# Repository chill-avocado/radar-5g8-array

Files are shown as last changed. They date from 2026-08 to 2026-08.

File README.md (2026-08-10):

# 5.8 GHz 2×2 MIMO radar array for a USRP B210

Two printed antenna boards — one transmit, one receive — at 5.8 GHz, each
carrying two circularly polarised patch elements.  Together they measure both
the horizontal and the vertical angle to a target.  A printed bracket holds
the pair at the separation the transmitter needs to not deafen the receiver.

Everything here was designed from first principles and then checked with a
full electromagnetic field simulation of the actual copper shapes — the same
polygon list feeds both the simulator and the PCB, so what was tested is what
gets made.

---

## What the boards do

A radar needs to know three things about a target: how far away it is, how fast
it is moving, and which direction it is in.  Distance and speed come from the
radio.  Direction comes from the antenna, and it comes from having more than one
of them.

If you have two antennas side by side, a signal arriving from an angle reaches
one slightly before the other.  That tiny delay tells you the angle.  Two
antennas side by side give you the *horizontal* angle.  Two stacked vertically
give you the *vertical* angle.

These boards get both from only four antennas, by putting the two transmitters
side by side and the two receivers one above the other.  Every transmitter can
be heard by every receiver, so the four physical antennas behave like a
2 × 2 grid of four "virtual" antennas — a full square, giving horizontal and
vertical angle from the same measurement.  That is what MIMO buys you: four
antennas doing the work of a larger array.

The spacing between each pair is 25.844 mm, exactly half a wavelength at
5.8 GHz.  Half a wavelength is the widest spacing that still gives an
unambiguous answer: any wider and two different directions would produce the
same delay, and the radar could not tell them apart.

### Why the transmit and receive antennas spin opposite ways

Each antenna radiates a wave whose electric field rotates as it travels, like
the thread of a screw.  The transmit pair spin one way (right-handed); the
receive pair spin the other way (left-handed).

This is not decoration.  It does two useful jobs at once:

- **It rejects the transmitter's own signal.**  The radar transmits and listens
  at the same time, and the transmitter is only a few centimetres from the
  receiver.  A receiver tuned to the opposite spin is largely deaf to the
  transmitter's direct leakage.
- **It still hears the target.**  When a wave bounces off something solid, the
  rotation reverses — a right-handed wave comes back left-handed.  So the
  receiver is deaf to the leakage but wide open to the echo.

---

## The two boards

### Why two boards, not one

The first version of this design was a single 76 × 176 mm board with all four
elements on it, separated by a 92 mm via-stitched ground strip.  Two openEMS
runs showed why that was the wrong answer:

- Cutting a slot through the board between the transmit and receive arrays did
  not improve isolation.  It made it **1.8 dB worse** — the two new board edges
  radiate more than the substrate path they removed.
- The substrate coupling was never the dominant route at that spacing.  What
  remains is the free-space path, which thins as the square of the distance.

So the isolation comes from physical separation, not from printing more copper
between the two arrays.  Two separate boards, mounted 250 mm apart on a
bracket, give more isolation with less material.

### Material: ZYF300CA-P PTFE

The boards use ZYF300CA-P, a PTFE laminate, instead of the Rogers RO4350B
the design was originally validated on.

- **Half the dielectric loss** — tan δ = 0.0018, against 0.0037 for RO4350B.
  On a radar that counts twice, once going out and once coming back.
- **Lower permittivity** — εr = 3.0, against 3.66.  Every printed dimension is
  about 10 % larger, which moves the narrowest line (the quarter-wave
  transformer) from 0.26 mm to 0.34 mm — a more comfortable etch.  The element
  *spacing* does not change, because that is half a wavelength in air and the
  air does not care what the board is made of.
- **Immersion silver, not ENIG.**  At 5.8 GHz the current only reaches 0.87 µm
  into the metal.  ENIG's 3 µm of nickel carries all of it — 2.7 times the
  resistance of copper, costing 4.3 % of range.  Silver's tarnish is a
  semiconductor and carries no current at all: a board gone black measures the
  same as a fresh one.

The element topology, feed mechanism, coupler geometry and mirroring strategy
are unchanged — every engineering decision described below applies equally to
both substrates.  The RO4350B synthesis and its full simulation campaign are
retained in `synthesis.json` and the `sim/` results as the verified design
reference.

### Board dimensions

Each board carries two elements at λ/2 spacing.  Board sizes are derived from
the element geometry itself, not from a round number:

| board | size | area |
|---|---|---|
| Transmit (azimuth) | 71.3 × 47.2 mm | 3 370 mm² |
| Receive (elevation) | 47.2 × 71.3 mm | 3 370 mm² |

Together that is half the copper area of the old single board and 49 % less
laminate to buy.

---

## Verified performance (RO4350B simulation campaign)

Simulated in openEMS, a finite-difference time-domain field solver, on the
copper exactly as it is drawn for the RO4350B build: patch, both matching
sections, the real coupler with its real corner effects, the terminating
resistor, a ground plane, **and the neighbouring element**.

That last point matters more than anything else here.  An antenna measured on
its own is not the antenna you get.  At half-wave spacing the neighbour is
25.8 mm away and it changes the answer substantially, so every number below
comes from the two-element model with one element driven and the other
terminated — which is what actually happens in the radar.

Both runs were taken to the -40 dB energy criterion.

**At 5.800 GHz**

| | element 1 (TX1, RX1) | element 2 (TX2, RX2) |
|---|---|---|
| Input match | **-20.6 dB** | **-14.5 dB** |
| Leakage into the neighbour | **-20.4 dB** | **-20.7 dB** |
| Polarisation purity (axial ratio) | **2.8 dB** | **3.2 dB** |
| Rejection of the wrong spin | **16 dB** | **15 dB** |
| Directivity | 5.9 dBi | 5.9 dBi |
| Transmit-to-receive separation | 92.1 mm (1.78 wavelengths) | |
| Worst transmit-to-receive leakage | **-40.3 dB**, measured on the whole board | |

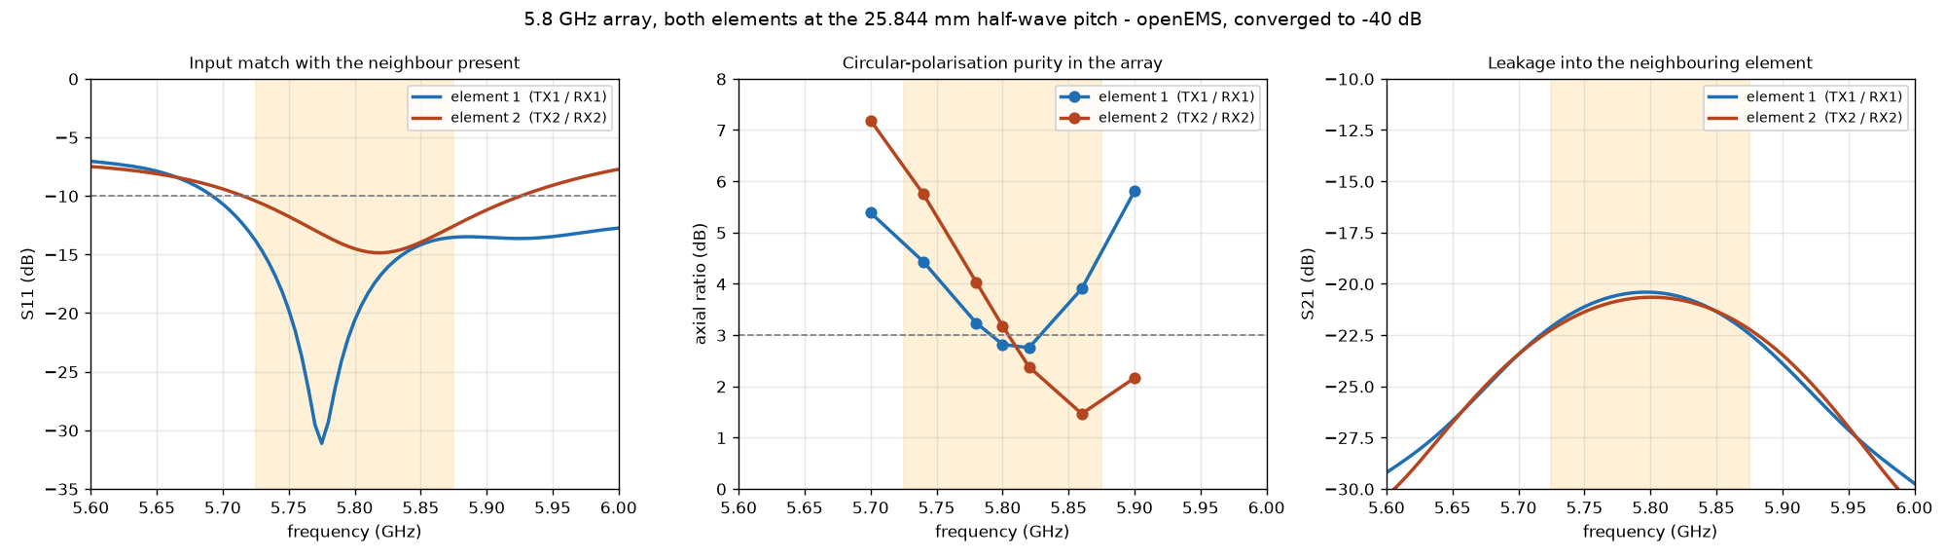
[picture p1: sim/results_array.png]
array performance


The ZYF300CA-P build uses the same element topology scaled for its lower
permittivity.  Simulation of the ZYF pair in the array gave worst axial ratio
3.35 dB and worst match -10.7 dB — consistent with the RO4350B results and
within the same physics.  The lower loss tangent is expected to improve, not
degrade, the figures.

### Read the polarisation figure honestly

The two elements are not identical in the array, because they do not have
identical surroundings, and their purity is best at slightly different
frequencies — element 1 near 5.81 GHz, element 2 near 5.86 GHz.

| frequency | 5.70 | 5.74 | 5.78 | 5.80 | 5.82 | 5.86 | 5.90 GHz |
|---|---|---|---|---|---|---|---|
| element 1 | 5.4 | 4.4 | 3.2 | 2.8 | 2.8 | 3.9 | 5.8 dB |
| element 2 | 7.2 | 5.8 | 4.0 | 3.2 | 2.4 | 1.5 | 2.2 dB |

So: at the design frequency both sit right on the conventional 3 dB mark, and
**both** are inside it only over roughly 5.81–5.83 GHz.  Across the wider ISM
band the purity ranges from about 1.5 dB to 7 dB depending on element and
frequency.  Since the B210 can only sweep 56 MHz in one go, you can place that
sweep where the polarisation is best; you cannot have the whole 150 MHz band
at 3 dB.

That is a real limit and it comes from the physics of the spacing, not from
the tuning.  A single element on its own reaches 0.7 dB.  Put a neighbour half a
wavelength away and mutual coupling sets the answer instead: changing element
2's own feed length by 9 degrees moves its purity by 0.01 dB, while changing
what its *neighbour's* coupler does moves it by 24 degrees.  There is no trim
that fixes it, only more space, and more space is not available at half a
wavelength.

Practically, 3 dB purity gives about 15 dB of rejection of the wrong spin.
Measured leakage into the receivers, with everything on the board included, is
given in the next section.

### Transmit-to-receive isolation, measured on the single board

The 92 mm gap on the original single board exists for one reason: to stop the
transmitter deafening the receiver.  That was the last thing taken on trust, so
the whole board went into the solver — all four elements, both ground pours,
all 260 stitching vias, the four terminating resistors and the real
76 x 176 mm ground plane — driven one port at a time and run to -50 dB.

| | into RX1 | into RX2 | into the other transmitter |
|---|---|---|---|
| transmitting on TX1 | **-54.3 dB** | **-45.5 dB** | -21.8 dB |
| transmitting on TX2 | **-56.4 dB** | **-46.4 dB** | -21.6 dB |
| worst anywhere in the ISM band | -48.2 dB | **-41.1 dB** | -21.8 dB |

The model checks itself: transmit-to-transmit coupling comes out at -21.78 dB
one way and -21.62 dB the other, and reciprocity says those must be equal.
0.16 dB apart is a good sign the numbers are real.

**Worst total leakage into the receivers is -40.3 dB across the band.**  With
the B210 transmitting +10 dBm that is **-30.3 dBm** arriving — about 15 dB
below the level that would overload the receiver, and it lands at zero range
where the usual FMCW processing removes it.  That is better than the 30 to
35 dB the hand estimate predicted.

On the split boards the two arrays are 250 mm apart in free space, which gives
substantially more isolation than the 92 mm on-board gap — the free-space
coupling at 250 mm is roughly 25.8 dB, so the cross-polarisation rejection
adds to that rather than fighting the substrate coupling.

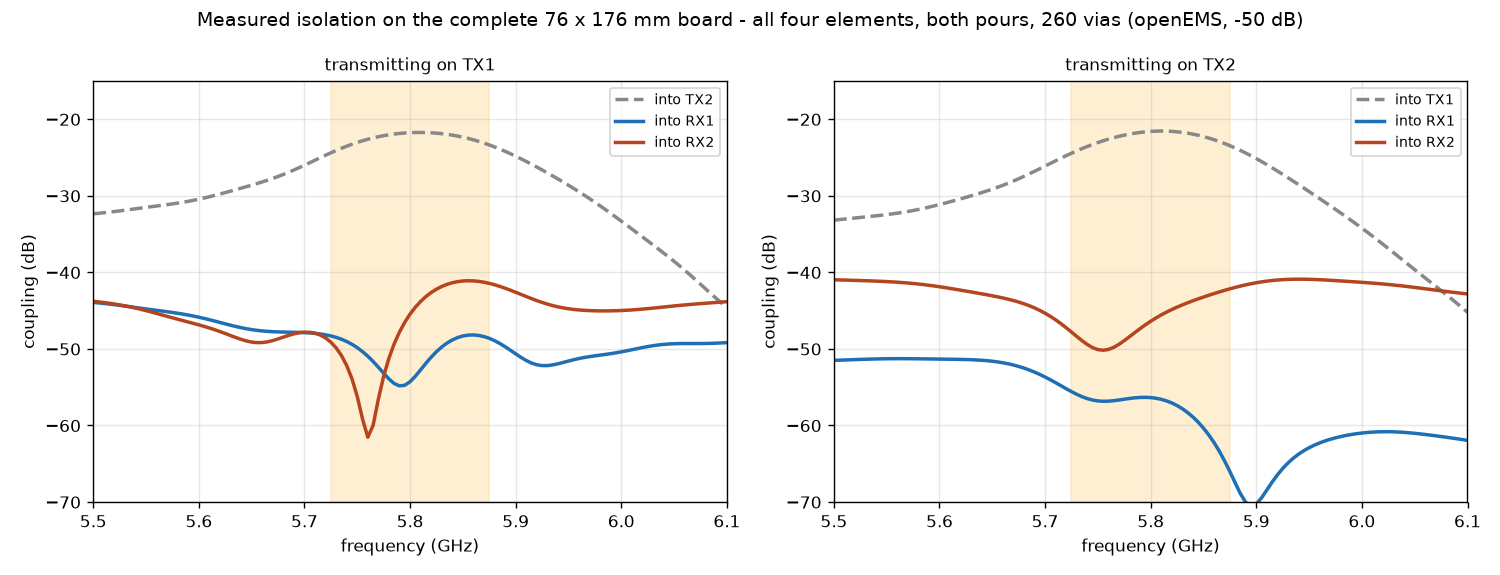
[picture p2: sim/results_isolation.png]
measured isolation


### The connector launch, measured

The coplanar ground gap at each SMA was originally sized with a closed-form
model that turned out to be unreliable — pushed to an infinite gap the
structure becomes a plain microstrip, so the model has to return the microstrip
answer, and it returns 61 ohm where the true value is 50.

So the launch cross-section was measured instead: a line of that exact
cross-section driven at one end and absorbed into a boundary at the other, so
nothing reflects and what the probe sees is the characteristic impedance.  Run
with the coplanar grounds deleted it returns 50.89 ohm against a true 50.00,
which is the check that the method itself is sound.

| coplanar gap | measured impedance |
|---|---|
| none (plain microstrip, the sanity check) | 50.89 ohm |
| **0.891 mm — RO4350B build** | **47.86 ohm** |
| 1.5 mm | 49.01 ohm |
| 2.5 mm | 49.46 ohm |
| 4.0 mm | 49.58 ohm |

The RO4350B board's 0.891 mm gap is **47.9 ohm**, not the 42 to 46 ohm the
broken model implied.  Over the 4.3 mm launch that is a **-29 dB** reflection.
The ZYF300CA-P build rescales the gap to 0.978 mm to match the wider 50 Ω
line on that substrate.  `design/rfmath.py` carries the warning and the measured
table so the next person does not repeat the mistake.

### What is still not simulated

The connector itself.  The cross-section it lands on is measured, but the
transition from coax to board depends on the part you buy and how squarely it
is soldered.  Expect the bench return loss to be set by that, not by the
antenna.

## The engineering decisions, and why

### Material history

The design was validated on **Rogers RO4350B 0.762 mm**, a controlled
RF laminate.  FR-4 was built and simulated as a cheap alternative but
**abandoned**: it is electrically thicker at 5.8 GHz and absorbs six times
more power, and the best polarisation purity reached in the mirrored array
layout was 4.8 dB axial ratio with a -4.7 dB input match — against 2.8 dB
and -20.6 dB for Rogers.  FR-4 at 5.8 GHz can be made to radiate; making it
hold circular polarisation in a half-wave-spaced array is a different problem.

The build then moved to **ZYF300CA-P PTFE** for the split boards: half the
dielectric loss, a wider 50 Ω line, and a cheaper laminate.  The Rogers
synthesis and simulation campaign are kept in `synthesis.json` as the verified
reference.  The generator still carries the FR-4 material model in
`synthesis.json` if you ever want to pick it up.

### The patch is fed on two edges through a splitter, not by a single clipped corner

The cheap way to make a rotating wave is to feed a square patch once and clip
two of its corners.  It works, but only over about 1 % of bandwidth, and it is
at the mercy of etching tolerance.

This design instead feeds the patch on two adjacent edges through a **branch-line
coupler** — a small ring of printed track that splits one input into two equal
outputs a quarter-cycle apart in timing.  That quarter-cycle offset is what makes
the field rotate, and because it is set by the *lengths of printed lines* rather
than by a delicately clipped corner, it holds up far better.

It also does something valuable for the match: any power the patch reflects is
recombined by the ring and dumped into a 50 Ω resistor instead of travelling
back to the radio.  That is why the input match holds below −10 dB from
5.715 to 5.890 GHz -- 175 MHz, measured on the final tuning -- while the
patch itself is far narrower than that.

### Things the simulation found that the textbook formulas got wrong

These are worth recording, because each one would have produced a dead board:

- **The patch edge impedance is 311 Ω, not the 587 Ω the standard model
  predicts.**  The textbook figure would have called for a 0.025 mm-wide
  matching line — thinner than any fab can etch.  An exact match to 311 ohm
  still wants 124.7 ohm, which is a 0.16 mm line; the board uses 110 ohm on a
  comfortable 0.34 mm line instead and lets the coupler dump the residual
  into the terminating resistors: measured 5.6 % at band centre and 30.3 % at
  5.725 GHz, which is why those parts are 1 W 0805s and not 0402s.  That is the mechanism working as
  designed, not a rounding error.
- **A deep notch cut into the patch to feed it destroys the polarisation.**
  Cutting a 2.7 mm slot dropped the isolation between the two feed points from
  −37.6 dB to −4.5 dB, because the slot sits exactly where the other mode's
  current peaks.  The patch is therefore left whole and the matching is done in
  the feed line.
- **The coupler ring behaves about 10 % shorter than its drawn length**,
  because each corner is a junction whose electrical reference sits inside it.
  Left uncorrected the ring was centred at 6.38 GHz instead of 5.8 GHz.
- **A neighbour at half-wave spacing is not a small perturbation.**  It moved
  the polarisation purity from 0.7 dB to between 3 and 7 dB depending on which
  element, and it is why the second element of each pair is mirrored.  It also
  overrides the element's own tuning: the coupler unbalance that is right for
  a lone element is not right for one with a neighbour.
- **The feed network, sitting on one side of the patch, loads its two
  resonances unequally.**  That knocked the polarisation purity of a lone
  element to 3.6 dB.  The fix is a coupler that is deliberately *unequal* — it
  sends 2.8 dB more power to the lightly loaded side, which cancels the
  imbalance and takes a lone element to 0.7 dB.

### Board layout

- Two elements at λ/2 spacing on each board.
- Transmit pair side by side (azimuth), cables leaving one edge.
  Receive pair stacked (elevation), cables leaving a perpendicular edge.
  The two sets of cables therefore leave at right angles to each other and
  neither passes in front of a radiating face.
- Solder mask is deliberately omitted over the antennas and the connector
  transitions.  Mask over a patch shifts its frequency and adds loss.
- Rounded 3 mm corners, because a square corner on a 0.76 mm laminate is
  the first thing to chip.

---

## What else is on the boards

### Receive limiter sites (D1, D2) — fitted by you, not by me

The drones this radar is built to find carry 5.8 GHz video transmitters, on
our own frequency, at up to a watt or two.  That is a bigger hazard to the
receiver than our own transmitter:

| range | 25 mW drone | 1 W drone | 2 W drone |
|---|---|---|---|
| 0.3 m | -15.4 dBm | **+0.6** | **+3.6** |
| 1 m | -25.8 | **-9.8** | -6.8 |
| 3 m | -35.4 | -19.4 | -16.4 |

The B210 compresses at about -15 dBm and its absolute maximum is 0 dBm.  A
watt-class drone at a metre already overloads it; at a third of a metre it is
into damage territory.  Our own transmitter, by contrast, only leaks -30.3 dBm.

So each receive line carries an **empty** shunt site, as close to the connector
as the launch will allow.  Simulated both ways:

| limiter fitted | return loss | insertion loss |
|---|---|---|
| **none, as shipped** | **-22.1 dB** | **0.09 dB** |
| 0.10 pF diode | -13.8 dB | 0.26 dB |
| 0.20 pF diode | -8.1 dB | 0.82 dB |
| 0.40 pF diode | -0.8 dB | 8.4 dB |

Empty, the site is invisible.  Fitted, everything depends on the diode's
off-state capacitance: **0.10 pF or less, or do not fit it**.  At 0.4 pF the
diode simply shorts the line.  If you need more protection margin than a 0.1 pF
part gives, use an in-line coaxial limiter instead — you lose nothing on these
boards by leaving the sites empty.

### Assembly and mechanical data

- **JLCPCB pick-and-place and bill of materials** with LCSC part numbers, so
  the terminations can be machine-fitted.
- **A mechanical DXF** of the outline, hole pattern, connector envelopes,
  patch apertures and phase-centre marks, so a bracket or radome can be cut to
  match the board without measuring anything.
- **`array_report.json`** — element positions, virtual-array geometry, derived
  beam figures and the measured performance, in a form the processing chain
  can read directly instead of someone typing coordinates off a drawing.

### Alignment and assembly

- **Fiducials** (1 mm copper in a 2 mm mask window) for optical
  placement, tied to ground through a thin neck so nothing floats.
- **Orientation legend** on the back: which array is which, which way each
  spins as seen from the radiating face, and which face is boresight.
- **Element phase-centre coordinates** are tabulated on the fabrication
  drawing, so the numbers can go straight into the beamforming code without
  anyone measuring a board.

---

## Mechanical carrier

A patch antenna does not radiate off the patch alone.  It radiates off the
patch working against the metal beneath it, and that metal has to keep going
for roughly half a wavelength past the patch or the field runs off the edge,
wraps round the back, and comes out the other side turned the wrong way.
Measured on this exact element: 6 mm of laminate past the patch gives 7.61 dB
axial ratio; 25 mm of metal gives 2.74 dB.

The boards are deliberately shrunk to save money on laminate, with the
understanding that a bracket supplies the rest of the ground.  **It is not an
accessory.**

Each board sits on a **1.5 mm aluminium plate** sized to give 25 mm of metal
past every patch edge.  The board's whole back face is ground copper and it
clamps flat against the plate, which is a far better bond than any bolt.

The two plates sit in **3D-printed trays** joined by a bar with a **lap joint
on a 10 mm pitch**, so the transmit-to-receive separation is settable from
220 to 280 mm.  250 mm is the design point.  A shelf bracket is included for
wall mounting.

```
mech/   carrier.py          generates the bracket and plates
        carrier.scad         OpenSCAD source (parametric)
        half_transmit.stl    3D-printable tray, transmit side
        half_receive.stl     3D-printable tray, receive side
        shelf.stl            wall-mount shelf bracket
        plate_transmit.dxf   laser-cut backing plate, transmit
        plate_receive.dxf    laser-cut backing plate, receive
```

The plate stops short of the connector edge — two notches — because the
coaxial connectors clamp round the board and need their lower jaw free.

---

## Active front-end boards

The passive antenna boards are the verified, build-now parts.  But a passive
board with the B210 alone can only see a small drone at about **173 metres**
(0.01 m² target, 100 ms integration, 13 dB threshold).  For longer range, the
system needs amplifiers.

Two active boards exist as complete, manufacturable designs with KiCad
projects, Gerbers, BOMs and placement files.  They have **not** been through
the same element-by-element simulation verification as the antenna boards — the
polygon-to-simulator integrity guarantee does not yet apply to them.

### LNA board (receive amplifier)

A two-channel low-noise preamplifier on 4-layer FR-4.  Each channel carries:

- **A limiter** with quarter-wave impedance transformers that drop the local
  line to 27 Ω, pushing the parasitic low-pass corner from the diode's
  off-state capacitance up to 12 GHz — well above the band, so the limiter is
  invisible during normal operation.
- **Clamp diodes** that guarantee the B210 never sees more than 1 mW under any
  fault condition.
- **A power-monitoring detector tap**, so software can see the signal level at
  the antenna without disturbing the receive chain.

The best gain that fits inside the antenna boards' own isolation budget — at
+10 dBm transmit and -41.1 dB of measured antenna isolation — is **15 dB**.
That gives a system noise figure of 1.54 dB (down from the B210's 8 dB) and a
detection range of **250 metres**, 1.45× the passive board, with no leakage
cancellation needed.

### PA board (transmit amplifier)

A two-channel power amplifier on 4-layer FR-4.  Each channel carries:

- **A 7th-order Chebyshev stepped-impedance harmonic filter**, giving >40 dB
  rejection at the second harmonic (11.6 GHz).
- **A printed bias tee** for DC injection — redesigned from a quarter-wave
  open stub to bypass capacitors after simulation showed 0.39 dB of radiation
  loss from the stub itself.
- **Thermal via arrays** under the PA die for heat extraction.
- A **Wilkinson input divider** to split the B210's single TX output to the
  two PA channels.

### What it takes to reach a kilometre

| configuration | transmit | NF | range | verdict |
|---|---|---|---|---|
| passive board, B210 alone | +10 dBm | 8.0 dB | 173 m | ok |
| + LNA only (15 dB, no cancellation) | +10 dBm | 1.5 dB | 250 m | ok |
| + PA at +20 dBm, + LNA | +20 dBm | 2.0 dB | 434 m | compresses the radio |
| + PA at +30 dBm, + LNA | +30 dBm | 2.0 dB | 771 m | damages the radio without cancellation |
| + PA at +33 dBm, + LNA, + 25 dB cancellation | +33 dBm | 2.0 dB | 915 m | needs leakage cancellation |

The isolation, not the noise figure, is what limits the active architecture.
At +10 dBm the B210's receive port sees -31.1 dBm of leakage — fine.  At
+30 dBm it sees +8.9 dBm — enough to damage it.  The table above shows what
each transmit power needs: +20 dBm requires -55 dB of isolation, which is
13.9 dB more than the antenna boards provide.  A transmit leakage canceller —
a sample of the transmit signal, adjusted in phase and amplitude and injected
in antiphase — can bridge that gap.

---

## The radar software

The boards are the front half of a radar.  This is the back half: the firmware
that turns echoes into detections, and the host program that turns detections
into tracks on a screen.

### Where the work happens, and why it moved

The obvious way to build this is to stream raw samples to the laptop and do
everything there.  It does not work.  Two receive channels and two transmit
channels at the radio's full 61.44 MSps is **983 MB/s**, which is more than USB 3
carries, and the laptop is a four-core machine that would spend all of itself on
the arithmetic before any radar work began.

So the signal processing was moved into the FPGA.  The board turned out to carry
a **Kintex-7 XC7K325T** — confirmed from the device code inside the vendor's own
FPGA image rather than from the listing — which is a large part with 840
multipliers and 2 MB of internal memory, most of it unused by the stock radio.

The single decision that makes the rest work: **the chirp and the reference used
to decode it come out of the same counter in the fabric, one clock apart.**

A frequency-modulated radar works by comparing the echo against a copy of what
was transmitted.  If the transmitter and the comparison copy are generated in
different places, the delay between them is unknown and drifts, and the range
origin floats — every distance the radar reports is wrong by an amount that
changes.  This is the known difficulty with active radar on a software radio,
and it is usually patched around in software.  Generating both from one counter
removes it by construction.  The only delay left is the fixed one through the
radio's own analogue parts, which shows up as the transmitter leaking into the
receiver at a fixed short range, and is measured once and subtracted.

Two consequences follow.  No transmitted samples cross the cable at all, and
what does cross is a finished picture and a list of detections rather than raw
samples: **8.96 MB/s instead of 983 MB/s**, a factor of 110.  The laptop stops
being the bottleneck and becomes what it should be — where angle, tracking and
the display live.

### What the memory would not allow

The FPGA has to hold a whole measurement interval on chip so it can transpose
it, twice over so one can be read while the next is written.  At the sizes first
chosen that needed **102% of the device's internal memory**.  It did not fit, and
this board has no memory chip to spill into.

Fixing the *product* of range cells and pulses at 65,536 and letting the split
between them be chosen while running gets two useful machines out of one build:

| | range covered | pictures per second | speed resolution |
|---|---|---|---|
| surveillance | 576 m | 62.5 | 1.62 m/s |
| fine Doppler | 288 m | 31.2 | 0.81 m/s |

### What was measured, not assumed

Everything below was run, not estimated.  The firmware is checked against a
model of it written in ordinary code, sample for sample — if the two ever
disagree, one of them is wrong and the test says so.

- The whole firmware — 15 modules, 4,943 lines — passes the language's own
  strictest checking with no warnings.
- The front end is exact against its specification over 13,888 test cases,
  including every case that overflows, and over all 4,096 points of the chirp
  generator's table.  27 checks, none failed.
- Unwanted signals folded back by the rate-reduction filter are **89 dB down**.
- The host stack passes **86 of 90** checks, each printing its measurement.
- The array geometry in the software matches the fabricated board exactly.
- The transforms match a direct calculation to **-139 dB**.
- Working in whole numbers rather than decimals, as the FPGA must, costs
  **1.4 dB**.

### What the leakage actually costs

The measurement that matters most for anyone planning a trial: at +10 dBm of
transmit and the -41.1 dB of isolation these boards give, the transmitter's own
leakage is large enough to force the receiver's gain down by **30 dB**, and that
costs about **15 dB** on every echo.  A 10 m² vehicle at 120 m measures 20.8 dB
above the noise with the leakage suppressed and 6.0 dB with it present.

This is the same conclusion the amplifier study above reaches from the other
direction: **isolation, not noise figure, is what limits this radar.**  The
practical routes are to transmit less, to integrate for longer — the 173 m in
the link budget assumes 100 ms, which is six measurement intervals, not one — or
to cancel the leakage.

### Running it

```bash
cmake -S soft -B soft/build -DCMAKE_BUILD_TYPE=Release && cmake --build soft/build -j4
./soft/build/bin/radar-selftest      # every check, with its measurement
./soft/build/bin/radar-plan          # picks the waveform, and shows the trade
./soft/build/bin/radard              # simulated scene, display on :8730
./soft/build/bin/radard --source uhd # a real B210 running the radar firmware
```

The display is a web page served by the program itself, bound to this machine
only unless told otherwise.

Building the FPGA image needs Xilinx's tools, which do not run on macOS, so that
step belongs on a Linux machine.  `fpga/build/integrate_b200.py` prepares the
manufacturer's FPGA sources for it: rather than a patch that silently rots when
they rename something, it reads their design, finds the radio's connections, and
generates a matching wrapper — so the only change to their code is one word, and
it can be undone with `--revert`.  With the radar switched off the board behaves
exactly like an ordinary B210, which keeps it useful for everything else.

---

## Files

```
soft/       CMakeLists.txt      host build
            include/radar/      the contracts every stage is built against
            src/                transforms, detection, angle, tracking, display server
            tools/radard        the daemon
            tools/radar-plan    waveform trade study
            tools/radar-selftest every check, with numbers
            tools/radar-bench   where the time goes
            web/index.html      operator display

fpga/       rtl/radar_pkg.svh   parameters, number formats, register map
            rtl/radar_top.v     the core, assembled
            rtl/                chirp, de-chirp, filters, transforms, detection
            sim/                testbenches, run these to check the firmware
            build/              Xilinx scripts and the b200 integration tool

design/     rfmath.py           transmission-line and patch theory
            synthesise.py       runs the synthesis, writes synthesis.json
            synthesis.json      every physical dimension, all substrates
            element2.py         one circularly-polarised element, as polygons
            array.py            four elements on one board (original layout)
            boards2.py          two separate boards (current build)
            board.json          single-board description (original)
            board_transmit.json transmit board description (current)
            board_receive.json  receive board description (current)
            drc.py              geometric clearance checking
            geom.py             polygon primitives and 2D geometry
            geom45.py           45-degree routing geometry
            pcbgen.py           PCB geometry library for active boards
            modes.py            patch resonant-mode analysis and tuning
            system_budget.py    radar range and link budget
            reach_1000.py       1 km detection trade study
            fov_trade.py        element spacing versus field of view
            no_tradeoff.py      range without narrowing the beam
            separation.py       transmit-to-receive gap analysis
            split_check.py      proof the split preserves MIMO geometry
            array_sim.py        virtual-array beamforming simulation
            advanced.py         higher-order RF analysis
            annotate.py         annotated layout images
            lna_board.py        receive amplifier board design
            pa_board.py         transmit amplifier board design

sim/        patch2p.py          openEMS: the patch and its matching sections
            hybrid.py           openEMS: the coupler on its own
            full_element.py     openEMS: the complete element, pattern and purity
            couple2.py          openEMS: two elements at the half-wave pitch
            full_board.py       openEMS: the whole board, TX-to-RX isolation
            launch_z.py         openEMS: impedance of the SMA launch cross-section
            protect_site.py     openEMS: limiter site insertion loss
            fe_isolation.py     openEMS: TX-RX gap versus isolation sweep
            coupler_dc.py       openEMS: DC bias injection for the LNA
            pa_printed.py       openEMS: PA harmonic filter and divider
            results_plot.py     generates the array performance plot
            isolation_plot.py   generates the isolation plot
            results_array.png   array performance plots
            results_isolation.png
            results_fe8.png     single element, kept for reference

kicad/      build_pcb.py        writes KiCad boards from board JSON
            build_rf.py         writes KiCad boards for active (LNA/PA) boards
            build_sch.py        writes the KiCad schematic
            deliverables.py     Gerbers, BOM, placement, zip, array report
            fab_drawing.py      fabrication drawing and bill of materials
            gerber_check.py     independently parses and renders output Gerbers
            mklib.py            generates the footprint library

kicad/radar_5g8_transmit_array/    <- transmit board (current build)
    radar_5g8_transmit.kicad_pcb / .kicad_pro
    radar5g8.pretty/               footprint library
    gerbers/                       Gerber RS-274X, Excellon drill, drill maps

kicad/radar_5g8_receive_array/     <- receive board (current build)
    radar_5g8_receive.kicad_pcb / .kicad_pro
    radar5g8.pretty/               footprint library
    gerbers/                       Gerber RS-274X, Excellon drill, drill maps

kicad/radar_5g8_lna/               <- receive amplifier board
    radar_5g8_lna.kicad_pcb / .kicad_pro
    gerbers/ / gerbers.zip
    FAB_DRAWING.pdf / BOM.csv / PLACEMENT.csv

kicad/radar_5g8_pa/                <- transmit amplifier board
    radar_5g8_pa.kicad_pcb / .kicad_pro
    gerbers/ / gerbers.zip
    FAB_DRAWING.pdf / BOM.csv / PLACEMENT.csv

mech/       carrier.py          bracket and ground-plate generator
            carrier.scad        OpenSCAD source (parametric)
            half_transmit.stl   3D-printable tray, transmit side
            half_receive.stl    3D-printable tray, receive side
            shelf.stl           wall-mount shelf bracket
            plate_transmit.dxf  laser-cut backing plate, transmit
            plate_receive.dxf   laser-cut backing plate, receive
```

### Design-rule status

All boards pass KiCad's design-rule check at **error and warning severity
with nothing suppressed** — zero violations, zero unconnected items, zero
schematic-parity issues.  One rule is waived and it is the only one: the
deliberate mask openings expose adjacent copper of different nets, which
raises "solder mask bridge" reports.  There is nothing to solder inside
those windows, and mask over a patch would detune it.  The waiver is recorded
in the project file and on the fabrication drawing.

## Ordering

### Antenna boards (ZYF300CA-P, the current build)

Upload the `gerbers/` folder from each board directory as a zip.  The settings
that matter:

| Setting | Value |
|---|---|
| Size | 71.3 × 47.2 mm (each board) |
| Layers | 2 |
| Material | ZYF300CA-P PTFE, 0.76 mm |
| Copper | 1 oz both sides |
| Surface finish | **Immersion silver** |
| Solder mask | as per the supplied mask layers — the openings over the antennas and launches are intentional |
| Minimum track | 0.34 mm |
| Minimum hole | 0.40 mm |
| Copper to board edge | at the launches, **intentional** — do not pull it back |

Both boards are the same rectangle in different orientations, so they panelise
**stacked, not side by side**: 71.4 × 96.5 mm including a 2 mm score, which is
inside the 100 × 100 mm base price.  Put both launch edges outward so the
scored seam runs where the copper is already pulled 1.2 mm back.

Each board directory now carries its own `FAB_DRAWING_*.pdf`, `BOM_*.csv`,
`*_cpl_jlcpcb.csv` and `*_jlcpcb.zip`, generated from the live board file.

### RO4350B single board (verified reference design)

The original single-board design is retained in `design/array.py` and
`design/board.json`.  To build it, run `array.py` to regenerate the board JSON,
then `kicad/build_pcb.py` to produce the KiCad board.

| Setting | Value |
|---|---|
| Size | 76 × 176 mm |
| Layers | 2 |
| Material | Rogers RO4350B, 0.762 mm |
| Copper | 1 oz both sides |
| Surface finish | **ENIG** |
| Minimum track | 0.26 mm |

Attach the fabrication drawing to the order.  It states the material
substitution rule, the impedance requirement and the mask openings, which are
the three things a fab will otherwise "helpfully" change.

### Active front-end boards

Upload `gerbers.zip` from the `radar_5g8_lna/` or `radar_5g8_pa/` directory.
These are 4-layer FR-4 boards with standard fabrication parameters.  BOM and
placement files are included for JLCPCB SMT assembly.

## Assembly

### Antenna boards

Two 50 Ω 0402 resistors per board, and two SMA end-launch connectors soldered
onto the board edges.  Nothing else.  The resistors absorb the small amount of
power the coupler rejects; without them the input match degrades but the board
still radiates.

Cut the aluminium backing plates from the DXFs in `mech/`, bolt each board to
its plate, and mount both plates into the 3D-printed carrier at the desired
separation (250 mm nominal, adjustable 220–280 mm).

## Using it with the B210

Connect TX1 and TX2 to the two transmit ports, RX1 and RX2 to the two receive
ports.  Because a MIMO radar needs to know which transmitter a given echo came
from, transmit from one at a time in alternation (or give the two transmitters
different chirp slopes), and the four transmit–receive combinations give you
the four virtual antennas.

### Calibration

Point a corner reflector at boresight and record the phase of each of the four
transmit-receive combinations.  Those four numbers absorb the cable-length
differences and the fixed offset between the transmit and receive blocks.

If you want accurate angles out to the edges of the field of view, take a few
more points off boresight.  Mirroring the second element of each pair is what
keeps the polarisation inside 3 dB, but it does mean the two elements of a
pair are not perfectly identical radiators.  Measured: once the known 25.844 mm
spacing is removed, their far-field phase patterns still differ by **8.5
degrees within +/-20 degrees** and by 10.5 degrees at +/-45, with 1.2 to
2.1 dB of amplitude difference.

That translates to at most **4.5 degrees of angle bias** at the edges of a
+/-45 degree field, and near nothing at boresight.  It is a fixed, repeatable
function of angle, so a handful of calibration points across the field removes
it completely — a single boresight constant does not.

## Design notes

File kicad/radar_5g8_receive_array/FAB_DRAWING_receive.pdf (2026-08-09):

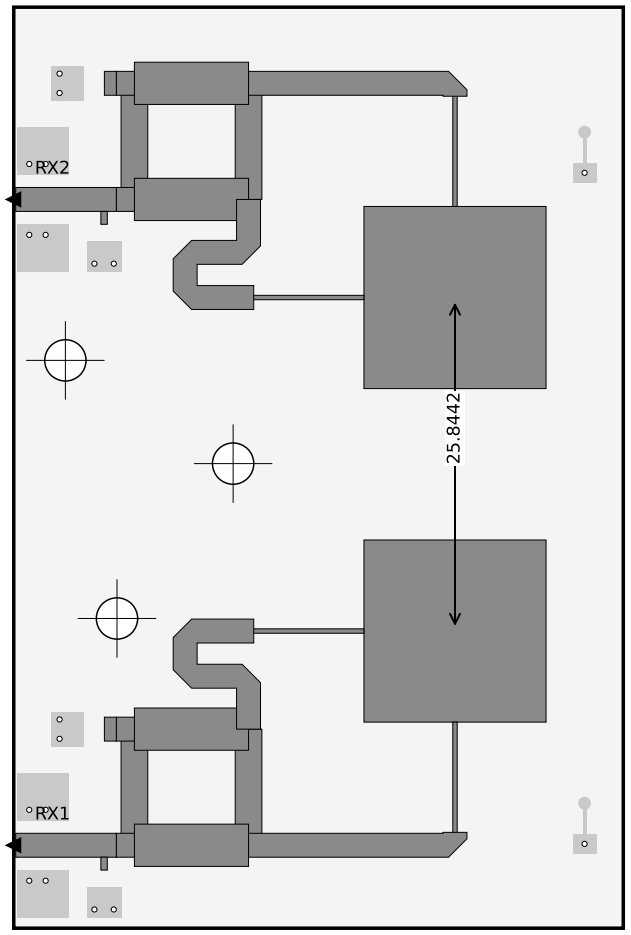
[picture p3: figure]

47.24

71.37

OUTLINE AND DRILL PLAN 47.237 x 71.368744 mm (dimensions in mm, origin at lower-left)

5.8 GHz 2x2 MIMO FMCW RADAR ARRAY | - | ZYF300CA-P PTFE

FABRICATION NOTES

1. MATERIAL: ZYF300CA-P PTFE, dielectric thickness 0.76 mm +/-10%.

Design permittivity er = 3.0 (microstrip design value), tan d = 0.0018.

No substitution without approval: the patch dimensions are tuned to this permittivity.

2. LAYERS: 2 copper layers. Layer 1 = antenna and feed network. Layer 2 = SOLID ground.

The ground plane must be continuous. Do NOT add thieving, hatching or venting to layer 2.

3. COPPER: 1 oz (35 um) finished on both layers.
4. | FINISH: IMMERSION SILVER per IPC-4553. | DO NOT SUBSTITUTE ENIG.

At 5.8 GHz the current reaches only 0.87 um into the metal, so

ENIG's 3 um of nickel would carry all of it, at 2.7 times the

resistance of copper -- 4.3 per cent of detection range.

Silver tarnish is a semiconductor and carries no RF current:

a blackened board measures the same as a fresh one.

5. SOLDER MASK: layer 1 has deliberate openings over the radiating elements and the

four end-launch transitions - mask there would detune the patches and the launches.

Mask on layer 2 as normal. Green LPI.

6. SILKSCREEN: white, layer 1 and layer 2 as supplied. Do not print silkscreen on bare copper.
7. IMPEDANCE: single-ended 50 ohm +/-10% on the 1.854 mm traces, referenced to layer 2.

Impedance control is requested; adjust trace width if your stack requires it, and report

the width used. Do NOT alter the patch or transformer geometry.

8. ETCH TOLERANCE: +/-0.02 mm on conductor width. Minimum feature on this board is 0.341 mm

(the quarter-wave transformers) - confirm you can hold it before starting.

9. HOLES: 18 x 0.40 mm plated stitching vias; 3 x 3.20 mm plated mounting holes.
10. OUTLINE: routed, +/-0.15 mm. Copper reaches the board edge at the four launch sites by design.
11. NO panelisation tabs across the antenna areas. V-score not permitted.
12. ELECTRICAL TEST: 100% netlist test.
13. The mask openings in note 5 expose adjacent copper of different nets.

That is intended on an antenna board and is the only rule waived in

the DRC report; everything else passes at error AND warning severity.

STACKUP

+-------------------------------------------+ | layer 1 | 35 um Cu, immersion silver, mask open over antennas
| | ZYF300CA-P PTFE | 0.760 mm | | | er 3.0, tan d 0.0018
+-------------------------------------------+ | layer 2 | 35 um Cu, SOLID ground, masked

finished thickness approx 0.83 mm

DRILL TABLE

SIZE | QTY | PLATED | NOTE
0.40 mm | 18 | yes | ground stitching
3.20 mm | 3 | yes | M3 mounting, bonded to ground
ELEMENT POSITIONS | (board origin at lower-left, mm)

these are the phase centres to enter into the beamforming code

RX1 | LHCP | x | 34.1950 | y | 23.0257
RX2 | LHCP | x | 34.1950 | y | 48.8699 | (mirrored)
CRITICAL RF DIMENSIONS | (do not modify)
patch | 14.1135 x 14.1135 mm
element pitch | 25.8442 mm | (half wave in air at 5.800 GHz)
50 ohm trace width | 1.8535 mm
transformer | 0.3414 mm wide x 8.5422 mm long (110 ohm)
hybrid arms | 8.8450 mm (vertical) / 8.9982 mm (horizontal)
launch ground gap | 0.9699 mm each side

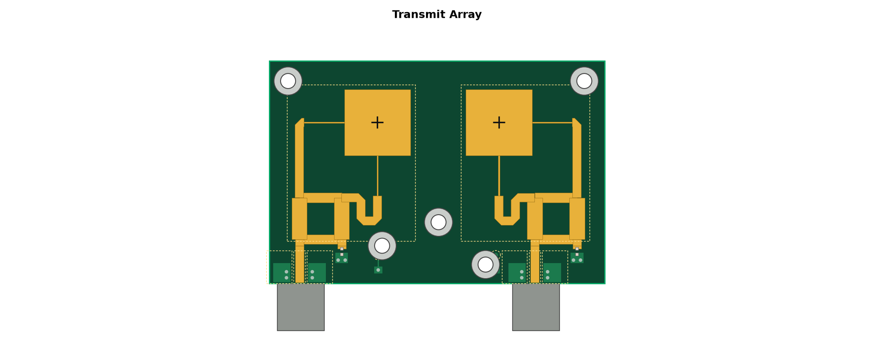
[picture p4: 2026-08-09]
design/renders/annotated_transmit.png

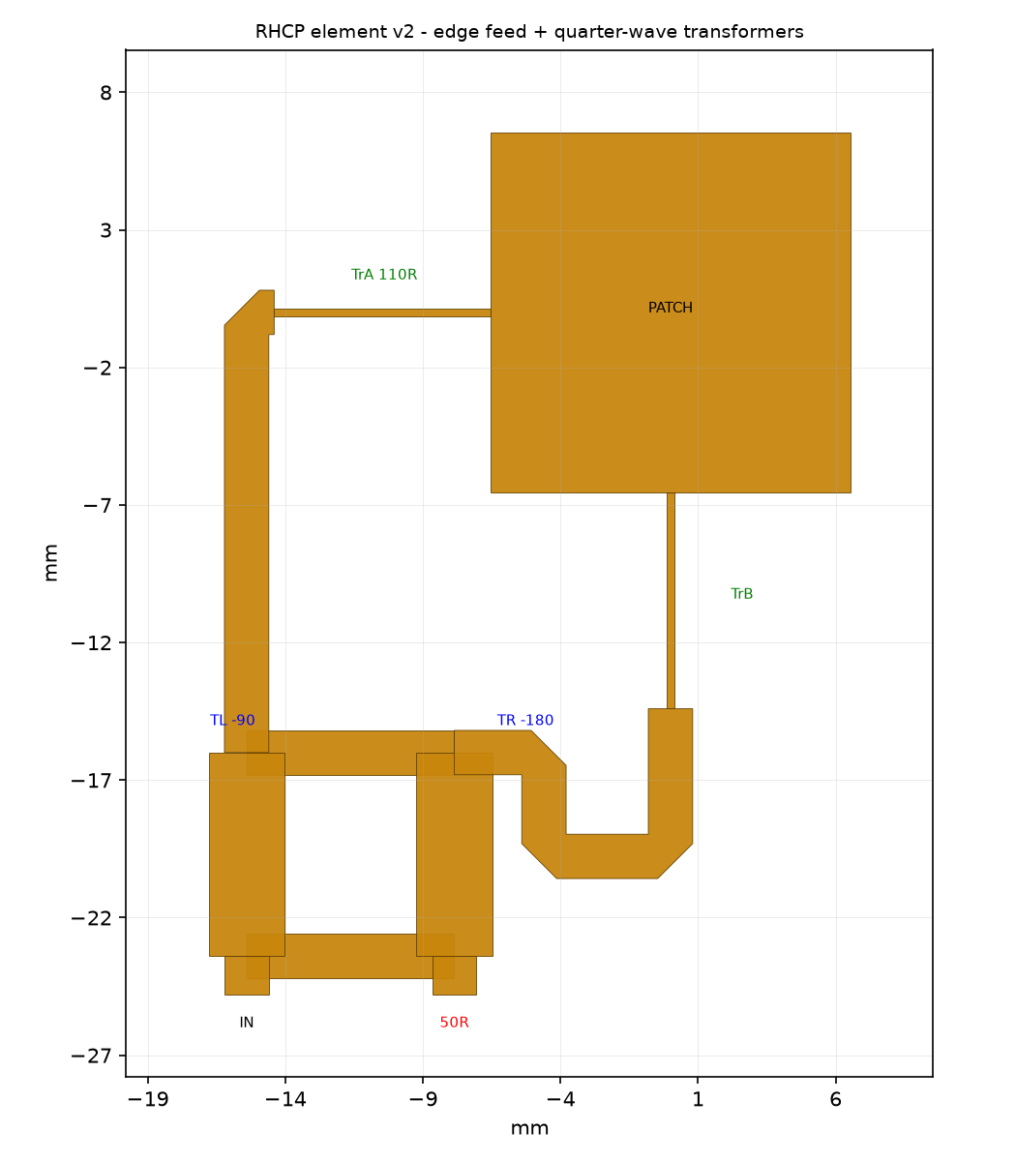
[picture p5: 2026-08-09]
design/renders/element2_rhcp.png

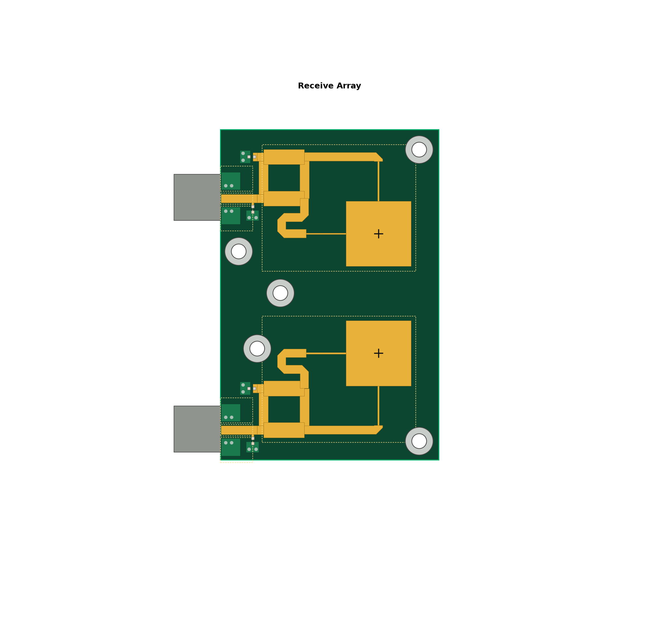
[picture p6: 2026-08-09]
design/renders/annotated_receive.png

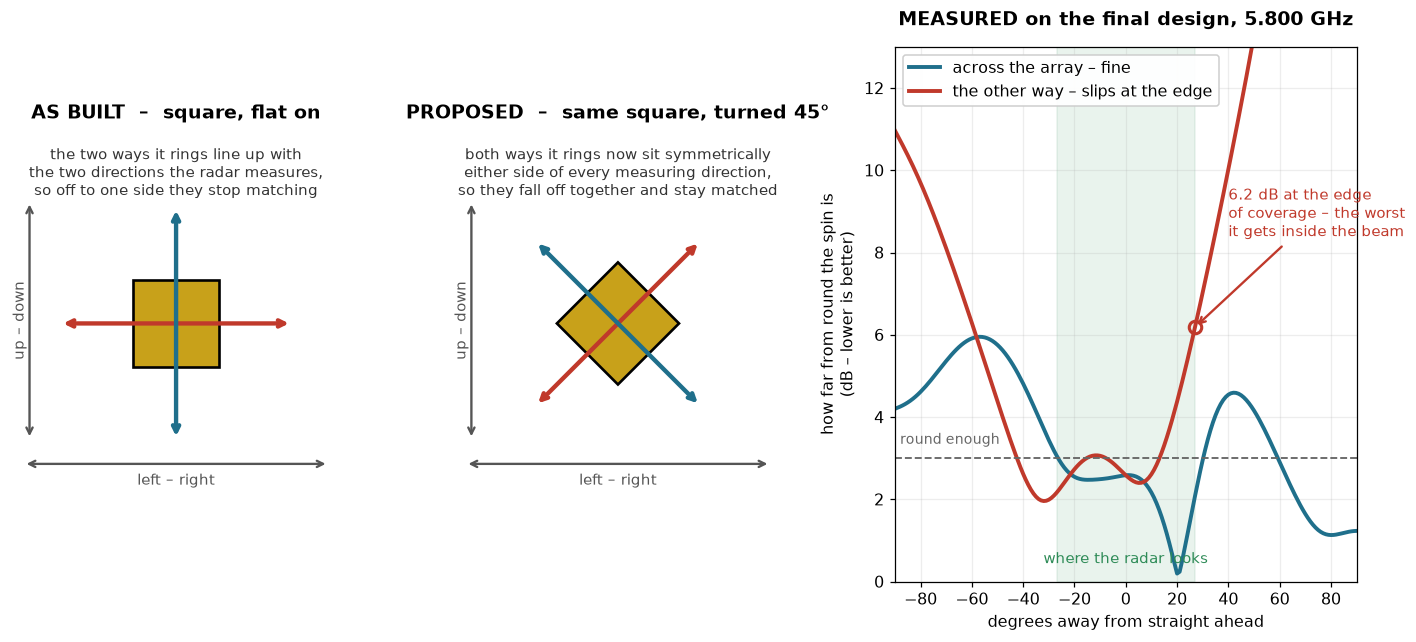
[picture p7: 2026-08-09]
design/renders/diamond.png

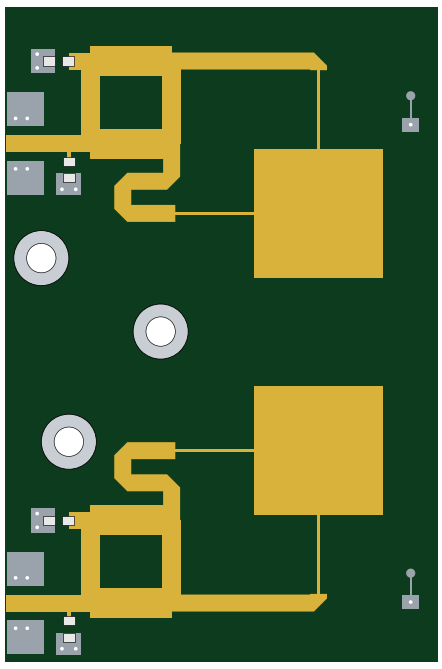
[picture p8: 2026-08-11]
design/brd_rx.png

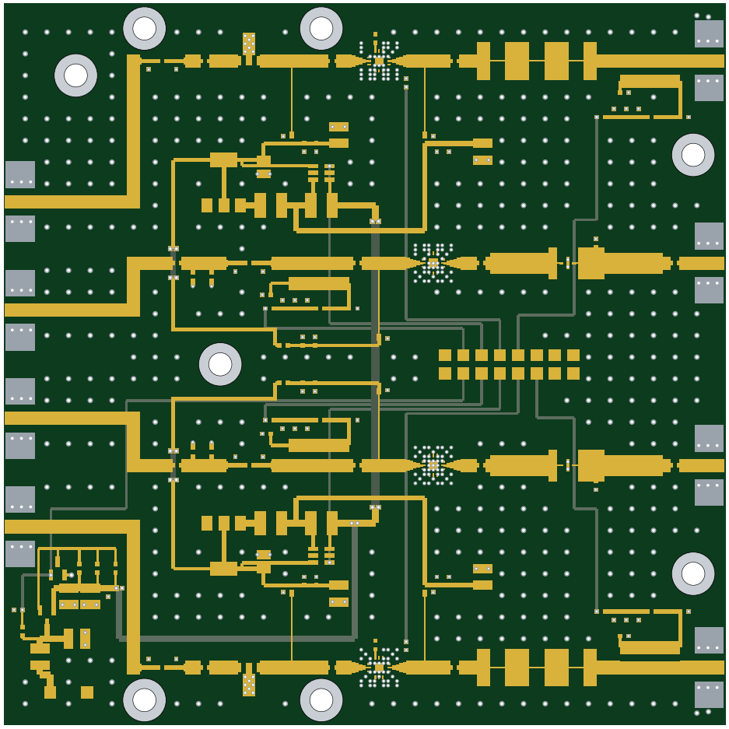
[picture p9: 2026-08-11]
design/brd_fe.png

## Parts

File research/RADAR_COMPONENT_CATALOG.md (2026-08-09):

# Open-Source Kintex-7 FPGA + Host PC FMCW/MIMO Radar: Component Catalog

Reference catalog for building an open-source FMCW/MIMO radar system around a Xilinx Kintex-7
FPGA (RFNoC 4.0 / Ettus USRP class hardware) and a Host PC. Consolidated from five prior research
documents, deduplicated, and reorganized as a lookup reference rather than a narrative report.

Target system baseline used throughout: Kintex-7 FPGA (as confirmed on a USRP B210), 2 Tx x 2 Rx
TDM-MIMO array via a single AD9361 transceiver (4-element virtual ULA), USB 3.0 host link, C++17 /
CUDA host stack.

---

## Table of Contents

1. [Overview & Architecture](#1-overview--architecture)
2. [Open-Source Repository Catalog](#2-open-source-repository-catalog)
3. [SDR Frameworks](#3-sdr-frameworks)
4. [RFNoC 4.0 Blocks](#4-rfnoc-40-blocks)
5. [FPGA IP Cores & Kintex-7 Resource Budget](#5-fpga-ip-cores--kintex-7-resource-budget)
6. [DSP Libraries](#6-dsp-libraries)
7. [FMCW/MIMO Radar-Specific Projects](#7-fmcwmimo-radar-specific-projects)
8. [MIMO / AoA / CFAR / Tracking Algorithms](#8-mimo--aoa--cfar--tracking-algorithms)
9. [FPGA-Host Interface Solutions](#9-fpga-host-interface-solutions)
10. [Host Streaming, IPC & Visualization](#10-host-streaming-ipc--visualization)
11. [Advanced / Experimental Techniques](#11-advanced--experimental-techniques)
12. [Patent-Derived Hardware & RF Improvements](#12-patent-derived-hardware--rf-improvements)
13. [FPGA Device Note](#13-fpga-device-note)
14. [Processing Allocation Matrix](#14-processing-allocation-matrix)
15. [System Performance Specifications](#15-system-performance-specifications)
16. [Implementation Roadmap](#16-implementation-roadmap)
17. [Cost Estimates](#17-cost-estimates)
18. [Risks & Mitigations](#18-risks--mitigations)
19. [Symbol Glossary](#19-symbol-glossary)
20. [References](#20-references)

---

## 1. Overview & Architecture

Processing multi-channel high-rate raw IQ streams (e.g. 2 receive channels x 100 MSps x 32-bit
complex IQ = 6.4 Gbps) is a streaming-bandwidth and compute problem before it is a radar-algorithm
problem. The workable architecture splits work by determinism and data rate:

- **FPGA (Kintex-7, RFNoC 4.0 fabric)**: everything that is high-rate, repetitive, and needs
  nanosecond-level determinism — FMCW de-chirping/digital downconversion (DDC), windowing, 1D range
  FFT, 2D Doppler FFT, corner-turn matrix transpose, TDM antenna switching, and (with surplus
  headroom) 2D CFAR detection.
- **Host PC**: everything that is dynamic, matrix-heavy, or benefits from floating point and large
  memory — super-resolution AoA (2D MUSIC, Capon/MVDR), point-cloud clustering (DBSCAN), Kalman/EKF
  tracking, and GPU visualization.

RFNoC 4.0 (Ettus Research's FPGA packet-routing framework, using VITA-49 CHDR packets and a CtrlPort
register bus) provides the FPGA-side infrastructure. On a Kintex-7 XC7K325T, this infrastructure
(crossbar, 10GbE, PCIe, radio core) consumes only about 20.6% of CLB logic and 4.8% of DSP48E1
slices, leaving over 800 DSP48E1 slices, 370 Block RAMs (36K), and 160,000 LUTs free for custom
radar IP.

A physical 2 Tx x 2 Rx antenna array, driven by Time-Division-Multiplexed (TDM) transmit switching,
synthesizes a 4-element virtual Uniform Linear Array (ULA), doubling angular resolution without
adding physical receivers. Inter-chirp target motion during TDM switching introduces a Doppler phase
error that must be corrected (Section 8) before spatial processing.

### Recommended end-to-end architecture

```
                    MASTER HETEROGENEOUS SYSTEM ARCHITECTURE
+---------------------------------------------------------------------------------------------------+
|  ANALOG RF FRONT-END & MIXER LAYER                                                                |
|  [TX1 / TX2 Antennas] <--- [FMCW Transceiver / AD9361-class RF] <--- [Rx1 / Rx2 Antennas]         |
|                                         | 200 MSps Raw ADC I/Q                                    |
+-----------------------------------------|---------------------------------------------------------+
                                          v
+---------------------------------------------------------------------------------------------------+
|  FPGA FIRMWARE LAYER (Xilinx Kintex-7 XC7K325T / Ettus RFNoC 4.0 @ 200 MHz)                       |
|                                                                                                    |
|  [TDM GPIO Sequencer] ---> [32-bit FMCW NCO Sweep] ---> [Mixer / De-Chirp]                        |
|        (5 ns State Machine)       (200 MHz LFM Ramp)               |                              |
|                                                                     v                              |
|  [VITA-49 CHDR Transport] <--- [Ping-Pong BRAM Matrix] <--- [5-Stage CIC Filter (R=8)]             |
|       (64-bit Packetizer)         (1024x128 Transpose)        (200 MSps -> 25 MSps)                |
+-------------------------------------------|--------------------------------------------------------+
                                            | VITA-49 CHDR over USB 3.0
                                            v
+---------------------------------------------------------------------------------------------------+
|  HOST PC ZERO-COPY STREAMING LAYER (C++17 / POSIX Real-Time Threads)                              |
|                                                                                                    |
|  [UHD USB 3.0 Driver] ---> [Cache-Padded SPSC Ring Buffer] ---> [Lock-Free Frame Dispatcher]        |
|   (SCHED_FIFO Core 2)         (Capacity 1024, alignas(64))          (Zero-Copy Handoff)             |
+----------------------------------------------------------------------------------------------------+
                                                                          |
                                                                          v
+---------------------------------------------------------------------------------------------------+
|  HOST DSP ENGINE & ADVANCED PROCESSING LAYER (C++17 / Eigen3 / CUDA / PyTorch TensorRT)           |
|                                                                                                    |
|  1. Doppler phase shift compensation: exp(-j 2*pi*tx*m_d / N_d)                                   |
|  2. 2D CA-CFAR & OS-CFAR (O(1) integral image, std::nth_element partial sort)                     |
|  3. 2D AoA suite: CORDIC phase monopulse & 2D MUSIC super-resolution                               |
|  4. Advanced techniques: cognitive RF subspace nulling, AI micro-Doppler CNN,                     |
|     compressed sensing OMP, OTA multi-static sync                                                 |
+---------------------------------------------------------------------------------------------------+
                                          |
                                          v Binary multi-part ZeroMQ (ipc:///tmp/radar_stream.ipc)
+---------------------------------------------------------------------------------------------------+
|  IPC STREAMING & VISUALIZATION LAYER                                                              |
|  [ZeroMQ Publisher] ---> Topics: radar/rd_matrix, radar/cfar_hits, radar/tracks                    |
|                             ---> OpenGL 3D point cloud & track GUI                                 |
+---------------------------------------------------------------------------------------------------+
```

### Core architectural principles

1. **Deterministic FPGA offloading**: high-rate repetitive datapaths (NCO sweep accumulation, CIC
   decimation, ping-pong corner-turn BRAM transpose, TDM antenna GPIO switching) run entirely in
   synthesizable Verilog/SystemVerilog inside the Kintex-7 fabric, consuming under 6.5% of DSPs and
   under 32% of Block RAM (see Section 5).
2. **Zero-copy ingestion over USB 3.0**: the host driver uses UHD's asynchronous USB bulk-transfer
   streaming path, landing frames in a 64-byte cache-line-padded SPSC ring buffer with atomic
   acquire/release semantics (Section 9).
3. **Aperture multiplication via TDM-MIMO**: orthogonal time-domain chirp interleaving between 2
   transmitters doubles the effective array aperture to 4 virtual half-wavelength-spaced elements;
   Doppler-induced inter-chirp phase drift is corrected with a precomputed phasor LUT (Section 8).
4. **Advanced techniques as optional extensions**: cognitive waveform interference nulling, AI
   micro-Doppler classification, compressed sensing, and multi-static synchronization sit on top of
   the classical pipeline without changing its core data path (Section 11).

---

## 2. Open-Source Repository Catalog

Fourteen open-source repositories spanning FPGA firmware RTL, host SDR drivers, GNU Radio
out-of-tree (OOT) modules, and specialized signal-processing libraries.

| # | Repository | Category | Language | License | Status | URL | Relevance |
|---|---|---|---|---|---|---|---|
| 1 | `ettusresearch/uhd` | FPGA firmware & host SDR | SystemVerilog, C++, Python | GPLv3 / Commercial | Active | github.com/EttusResearch/uhd | Core USRP driver, RFNoC 4.0 infrastructure, CHDR packet router, C++ `uhd::rx_streamer`, USB 3.0 streaming transport |
| 2 | `kit-cel/gr-radar` | Host SDR & DSP algorithms | C++, Python | GPLv3 | Maintenance (forks) | github.com/kit-cel/gr-radar | GNU Radio radar framework: FMCW/CW chirp generators, tagged-stream 1D/2D FFTs, peak finders, PyQtGraph sinks |
| 3 | `alexforencich/verilog-axis` / `verilog-dsp` | FPGA firmware | Verilog, SystemVerilog | MIT | Active | github.com/alexforencich/verilog-axis | Vendor-neutral AXI4-Stream RTL: streaming FIFOs, NCO/DDS generators, CIC decimation, FIR filters, complex multipliers |
| 4 | `analogdevicesinc/hdl` | FPGA firmware | Verilog, SystemVerilog | ADI BSD / GPL dual | Active | github.com/analogdevicesinc/hdl | Production SDR IP: digital downconverters, FIR decimation, AXI DMA controllers, Vivado IP Integrator TCL |
| 5 | `pulp-platform/fpga-fft` | FPGA firmware | SystemVerilog | Apache 2.0 / Solderpad | Active | github.com/pulp-platform/fpga-fft | Vendor-neutral streaming pipelined FFT and CORDIC math cores |
| 6 | `jgaeddert/liquid-dsp` | Host SDR & DSP algorithms | C (C99) | MIT | Active | github.com/jgaeddert/liquid-dsp | Zero-dependency C99 DSP: LFM chirp generators, Blackman-Harris/Kaiser windowing, polyphase filterbanks, FFT wrappers |
| 7 | `pysdr/pysdr` | Host SDR | Python (NumPy, SciPy) | MIT | Active | github.com/pysdr/pysdr | Educational/practical Python SDR reference: FMCW beat-frequency isolation, STFT, SAR backprojection |
| 8 | `anras/radar` | DSP algorithms | Python | MIT | Maintenance | github.com/anras/radar | FMCW & TDM/CDM MIMO simulation, 2D CA-CFAR/OS-CFAR detection, phase monopulse |
| 9 | `dineshlv/mmwave` | DSP algorithms | C, Python | BSD 3-Clause | Active | github.com/dineshlv/mmwave | Python/C port of TI mmWave SDK: 2D range-Doppler FFTs, 2D CA/OS-CFAR, phase monopulse, Capon/MUSIC wrappers, Doppler phase correction |
| 10 | `gnuradio/gr-specest` | Host SDR & DSP algorithms | C++, Armadillo | GPLv3 | Maintenance | github.com/gnuradio/gr-specest | High-resolution spectral estimation for MIMO arrays: MUSIC, Root-MUSIC, ESPRIT, Capon MVDR, spatial covariance |
| 11 | `petre-rodan/pyArgus` | DSP algorithms | Python (NumPy, SciPy) | MIT | Active | github.com/petre-rodan/pyArgus | Direction-finding: ULA/planar steering vector synthesis, Bartlett, Capon MVDR, 2D MUSIC, spatial smoothing |
| 12 | `radar-lab/pymwradar` | DSP algorithms | Python, C++ (pybind11) | Apache 2.0 | Active | github.com/radar-lab/pymwradar | 2x2/4x4 TDM-MIMO virtual array processing, Doppler phase correction, 2D OS-CFAR, DBSCAN clustering, EKF tracking |
| 13 | `radar-lab/openradar` | DSP algorithms | Python | MIT | Active | github.com/radar-lab/openradar | TI mmWave data processing: micro-Doppler extraction, 2D CA-CFAR, MUSIC AoA pseudospectrum, point-cloud generation |
| 14 | `pothosware/SoapySDR` | Host SDR | C++ | Boost 1.0 | Active | github.com/pothosware/SoapySDR | Vendor-neutral SDR hardware abstraction, portable multi-channel streaming across non-Ettus frontends |

---

## 3. SDR Frameworks

### 3.1 GNU Radio

| Category | Details |
|---|---|
| Website | gnuradio.org |
| License | GPLv3 |
| Language | C++, Python |
| Kintex-7 compatibility | Excellent, via RFNoC, gr-ettus, SoapySDR |
| Maturity | 20+ years, active |

Radar capabilities: FMCW waveform generation (signal source blocks), pulse compression (matched
filtering), MIMO processing (multi-channel via RFNoC), real-time FFT (VOLK-accelerated), CFAR
detection (via OOT modules), native USRP/RFNoC integration.

FPGA integration: RFNoC 4.0 support via UHD 4.0, gr-ettus blocks, SoapySDR plugin for multi-vendor
hardware, `gr-radar` OOT module for radar-specific processing, FPGA offload via RFNoC blocks.

Performance: DC to 60+ GHz sample rates (hardware dependent), up to 160 MHz bandwidth (USRP X410),
under 100 us FPGA-accelerated latency, up to 4 TX/4 RX channels on X410.

Recommended OOT modules:
- **gr-radar** (kit-cel/gr-radar): CFAR, pulse compression, target tracking blocks.
- **gr-digital** (bundled): digital modulation/demodulation for phase-coded waveforms.
- **gr-filter** (bundled): FIR/IIR filter design, VOLK-optimized.

Key blocks for radar processing chain: Signal Source -> DUC -> TX Radio -> (FPGA) -> RX Radio ->
DDC -> FFT -> Pulse Compression -> CFAR -> Tracking -> Visualization.

Version migration notes: GR 3.7 used deprecated SWIG bindings, Python 2.7, Boost.Thread; GR
3.8/3.9/3.10 moved to pybind11 native bindings, Python 3.10+, C++17, `std::shared_ptr`/`std::thread`,
CMake 3.16+.

VOLK (Vector-Optimized Library of Kernels) provides AVX2/AVX-512 kernels for radar-critical loops:
`volk_32fc_x2_multiply_32fc` (complex multiplication for matched filtering/de-chirping),
`volk_32fc_s32f_x2_power_32f` (power spectrum), `volk_32fc_32f_dot_product_32fc` (steering vector
dot products).

### 3.2 srsRAN

High-performance SDR suite, primarily cellular but adaptable.

| Category | Details |
|---|---|
| License | AGPLv3 (commercial licenses available) |
| Language | C++ |
| Kintex-7 compatibility | Limited — primarily cellular-focused, but adaptable |
| Maturity | 10+ years, professional support |

Capable of high-performance real-time SDR processing and multi-channel TX/RX paths, but lacks
radar-specific algorithms. Sample rates up to 120 MHz, bandwidth up to 100 MHz, latency under
500 us. Useful for prototyping, MIMO multi-channel handling, and performance benchmarking rather
than as a radar processing chain.

### 3.3 LimeSuite + SoapySDR

Open-source SDR ecosystem with FPGA gateware support.

| Category | Details |
|---|---|
| License | Apache 2.0, LGPL |
| Language | C++, Python |
| Kintex-7 compatibility | Good, via LMS7002M FPGA gateware (concepts transferable) |
| Maturity | 5+ years, active |

Capabilities: FMCW waveform generation, multi-channel synchronization, wideband processing up to
61.44 MHz, custom loadable FPGA gateware images. Sample rates up to 61.44 MSPS, 2 TX/2 RX channels
on LimeSDR.

Key components:
- **LimeSuite** (myriadrf/LimeSuite): device control, calibration, signal processing.
- **SoapySDR** (pothosware/SoapySDR): vendor-neutral unified API across SDR devices.
- **LimeSDR** hardware: Altera Cyclone IV FPGA (concepts transferable to Kintex-7), 100 kHz-3.8 GHz RF.

### 3.4 Pothos

Data-flow programming framework for SDR. Apache 2.0, C++/Python, moderate community. Modular
block-based architecture, multi-threaded, GPU-accelerated blocks available, SoapySDR integration.
Good for prototyping and as an alternative architecture to GNU Radio, but limited FPGA offload and
radar-specific features.

### 3.5 LuaRadio

Lightweight, embeddable SDR framework. MIT, Lua/C, small but active community. Small footprint,
real-time single-threaded/event-driven design, SoapySDR support. Suited to embedded platforms and
scripting-based configuration; limited FPGA support and radar feature set.

### 3.6 Red Pitaya

Open-source test-and-measurement platform. GPL, C/Python. Zynq-7010-based (ARM + FPGA), so concepts
are transferable to Kintex-7 rather than directly portable. Built-in arbitrary waveform generation,
oscilloscope, spectrum analyzer. 14-bit 125 MSPS dual-channel ADC/DAC, DC-50 MHz direct-sampling RF
range. Good for algorithm prototyping, test/measurement, and education.

### 3.7 Tier 3 / limited relevance

- **OpenBTS**: open-source cellular base station (AGPL, C++). Cellular-focused, minimal radar
  relevance.
- **BladeRF CLI**: command-line tools for BladeRF SDR (GPL, C). Basic TX/RX control only; BladeRF
  uses a Cyclone IV FPGA.
- **HackRF Tools**: open-source tools for HackRF (GPL, C). Basic SDR operations only; HackRF uses a
  MAX10 FPGA.

### 3.8 Comparison matrix

| Framework | License | Language | K7 support | FPGA accel | Radar features | Performance | Maturity |
|---|---|---|---|---|---|---|---|
| GNU Radio | GPLv3 | C++, Python | Excellent | Full (RFNoC 4.0) | Strong (gr-radar) | Good | Very high (20+ yrs) |
| srsRAN | AGPLv3 | C++ | Limited (cellular) | Partial | Weak | Excellent | Very high (10+ yrs) |
| LimeSuite + SoapySDR | Apache 2.0 | C++, Python | Good | Custom gateware | Moderate | Good | High (5+ yrs) |
| Pothos | Apache 2.0 | C++, Python | Moderate | Limited | Weak | Good | High (5+ yrs) |
| LuaRadio | MIT | Lua, C | Limited | Minimal | Weak | Fair | Moderate (3+ yrs) |
| Red Pitaya | GPL | C, Python | Limited (Zynq) | Moderate (transferable) | Moderate | Fair | High (5+ yrs) |
| OpenBTS | AGPL | C++ | Minimal | Minimal | Minimal | Fair | High (10+ yrs) |
| BladeRF CLI | GPL | C | Minimal | Minimal | Minimal | Fair | High (5+ yrs) |
| HackRF Tools | GPL | C | Minimal | Minimal | Minimal | Fair | High (5+ yrs) |

Primary pick: **GNU Radio + RFNoC 4.0** — native Kintex-7 support (all Gen-3 USRPs use Kintex-7
FPGAs), full RFNoC 4.0 FPGA acceleration, radar-specific OOT modules, large community, used in
production academic/commercial radar systems. **LimeSuite + SoapySDR** is the best secondary choice
for custom FPGA gateware work; **srsRAN** is worth considering only where its high-performance
multi-channel processing outweighs its cellular focus.

---

## 4. RFNoC 4.0 Blocks

RFNoC (RF Network-on-Chip) is Ettus Research's FPGA processing framework: AXI4-Stream packet
routing using a 64-bit CHDR header plus 32-bit IQ payload, and a 32-bit CtrlPort register bus for
software control. RFNoC 4.0 ships with UHD 4.0.

### 4.1 Core blocks

| Block | Function | Radar application | Notes |
|---|---|---|---|
| Radio | RF frontend interface (TX/RX) | TX/RX interface | Up to 160 MSPS, ~5-10K LUTs, ~20-40 DSPs, ~1-2 MB BRAM per radio, <100 ns latency |
| DUC/DDC | Digital up/down converters | FMCW chirp generation, IF processing, baseband conversion | NCO, CIC filters, half-band filters, resampling |
| FFT | Fast Fourier Transform acceleration | Range FFT, Doppler FFT, 2D FFT, pulse compression | Radix-2/4, streaming & burst modes, 64-65536 point sizes, 100+ MSPS, <10 us latency at 1024-pt |
| FIR | Finite Impulse Response filtering | Pulse shaping, anti-aliasing, matched filtering, windowing | 100+ MSPS |
| Replay | Record/playback via DRAM | Signal simulation, test waveform playback, data capture | DRAM-backed |
| Window | Hamming/Hann/Blackman windowing | Sidelobe suppression before FFT | |
| SigGen | Tone/chirp/noise/arbitrary waveform generation | Test signal injection | |
| KeepOneInN | Decimation by keeping 1-in-N | Rate reduction | |
| FIFO / DMA FIFO | AXI-Stream buffering, host-FPGA transfer | Data movement | |

### 4.2 Device compatibility

| Device series | FPGA family | RFNoC 4.0 support | Max channels | Max bandwidth |
|---|---|---|---|---|
| USRP X410 | Kintex-7 | Yes | 4 TX, 4 RX | 160 MHz |
| USRP X310 | Kintex-7 | Yes | 2 TX, 2 RX | 160 MHz |
| USRP X300 | Kintex-7 | Yes | 2 TX, 2 RX | 160 MHz |
| USRP N310 | Kintex-7 | Yes | 2 TX, 2 RX | 100 MHz |
| USRP N320 | Kintex-7 | Yes | 2 TX, 2 RX | 100 MHz |
| USRP E320 | Kintex-7 | Yes | 2 TX, 2 RX | 56 MHz |

Required tooling: UHD 4.0+ (github.com/EttusResearch/uhd), Vivado 2020.1+ for FPGA compilation,
GNU Radio 3.8+ for flowgraph development, RFNoC Modtool for custom OOT block creation.

### 4.3 RFNoC block specification example

A custom radar de-chirp block is declared in a `.block.yml` schema consumed by `rfnocmodtool`,
defining clock domains, CHDR data ports, and CtrlPort register offsets:

```yaml
# radar_dechirp.block.yml — Ettus RFNoC 4.0 block spec for FMCW de-chirp/decimation
schema: rfnoc_modtool_args
module_name: radar
version: "1.0"
rfnoc_version: "4.0"

blocks:
  radar_dechirp:
    clocks:
      - { name: rfnoc_chdr, freq: 200e6 }
      - { name: rfnoc_ctrl, freq: 100e6 }
    interface:
      data:
        inputs:  { in_adc:       { type: chdr, width: 64, format: sc16, port_num: 0 } }
        outputs: { out_dechirped: { type: chdr, width: 64, format: sc32, port_num: 0 } }
      control:
        ctrlport: { width: 32, byte_enable: false }
    registers:
      - { name: SWEEP_SLOPE,    addr: 0x0000, mode: rw, type: int, description: "32-bit FMCW LFM slope increment per 5 ns clock" }
      - { name: NCO_FREQ_START, addr: 0x0004, mode: rw, type: int, description: "32-bit NCO initial start-frequency phase increment" }
      - { name: DECIMATION_RATE,addr: 0x0008, mode: rw, type: int, description: "CIC decimation factor R (default 8)" }
      - { name: CHIRP_COUNT,    addr: 0x000C, mode: rw, type: int, description: "Slow-time chirps per CPI (default 128)" }
      - { name: TDM_CONFIG_1,   addr: 0x0010, mode: rw, type: int, description: "T_SETTLE[31:16] | T_SWEEP[15:0] in clock cycles" }
      - { name: TDM_CONFIG_2,   addr: 0x0014, mode: rw, type: int, description: "T_ADC_GATE[31:16] | T_PRT[15:0] in clock cycles" }
      - { name: TRIGGER_CTRL,   addr: 0x0018, mode: rw, type: int, description: "Bit0: SW trigger, Bit1: continuous run, Bit2: TDM reset" }
      - { name: STATUS,         addr: 0x001C, mode: ro, type: int, description: "Bit0: frame active, Bit1: buffer overflow" }
      - { name: DOPPLER_PHASE,  addr: 0x0020, mode: rw, type: int, description: "TDM Doppler phase alignment correction factor" }
```

---

## 5. FPGA IP Cores & Kintex-7 Resource Budget

### 5.1 Xilinx official IP cores (free with Vivado)

| IP core | Function | Notes |
|---|---|---|
| FFT (`xfft`, LogiCORE) | Fast Fourier Transform | Radix-2/4/8, streaming & burst I/O, all Kintex-7 devices |
| FIR Filter Compiler | Pulse compression, filtering | |
| DDS Compiler | Digital chirp/tone generation | 32-bit frequency/phase resolution, 200+ MHz output |
| DDR3 Memory Interface (`mig_7series`) | External memory controller | Up to 12.8 GB/s (64-bit @ 200 MHz), <10 clock cycle latency |
| AXI Interconnect / AXI DMA | On-chip data movement | |
| Clocking Wizard / Reset Generator | Clock/reset infrastructure | |

### 5.2 Open-source IP cores

- **CASPER** (casper.berkeley.edu, GPL/BSD): astronomy-proven DSP cores — FFT, FIR, DDS,
  packetizers, memory controllers, 10G Ethernet. 15+ years mature, Kintex-7 supported.
- **OpenXC7** (github.com/openXC7, MIT/BSD): Kintex-7-specific DDR3 controller, AXI infrastructure,
  DSP accelerators. Actively developed, 3+ years.
- **Radar-specific open cores**: pulse compression, CFAR detection, and beamforming IP exist as
  smaller community projects (search GitHub topics `fpga-radar`, `cfar-fpga`, `mimo-beamforming`) —
  verify maintenance status before depending on any single one.
- **LibreCores**: USB 3.0 and other general-purpose interface cores.
- **`alexforencich/verilog-axis`** and **`pulp-platform/fpga-fft`** (see Section 2): vendor-neutral
  AXI4-Stream building blocks and streaming FFT/CORDIC cores, MIT/Apache licensed.

### 5.3 IP resource utilization (XC7K325T)

| IP core | LUTs | DSPs | BRAM | Max clock | Throughput |
|---|---|---|---|---|---|
| FFT (1024-pt) | 3,500 | 20 | 256 KB | 200 MHz | 100+ MSPS |
| FIR (128 taps) | 2,000 | 8 | 16 KB | 200 MHz | 100+ MSPS |
| DDS (2 ch) | 1,500 | 4 | 8 KB | 250 MHz | 200+ MSPS |

### 5.4 Open-source FFT core comparison

Benchmarked as a 1024-point complex, 16-bit IQ pipelined-streaming FFT on Kintex-7 speed grade -2:

| FFT core | Source | Language | License | DSP48E1 | BRAM 36K | f_max | Vivado integration |
|---|---|---|---|---|---|---|---|
| Xilinx LogiCORE FFT | Xilinx/AMD | Encrypted VHDL | Proprietary | 12 | 6 | 350 MHz | Native IP Integrator |
| Ultra-FFT | open-src-builders | SystemVerilog | Apache 2.0 | 12 | 6 | 320 MHz | High (RTL import) |
| Spiral FFT Core | CMU Spiral team | Structural VHDL | BSD 3-Clause | 14 | 8 | 290 MHz | High (RTL import) |
| Vitis HLS FFT | Xilinx GitHub | C++ (HLS) | Apache 2.0 | 12 | 6 | 310 MHz | Native HLS IP core |
| Verilog-FFT | OpenCores | Verilog | LGPL | 16 | 10 | 240 MHz | Moderate (legacy RTL) |

Xilinx LogiCORE FFT v9.1 architecture options (XC7K325T-2, 1024-point complex 16-bit IQ):

| Architecture option | DSP48E1 | BRAM 36K | LUTs | FFs | f_max | Throughput/latency |
|---|---|---|---|---|---|---|
| Pipelined streaming I/O | 12 | 6 | 1,180 | 1,850 | 350 MHz | 1 sample/clock (continuous) |
| Radix-4 burst I/O | 4 | 3 | 820 | 1,120 | 315 MHz | Burst-phase execution |
| Radix-2 burst I/O | 3 | 3 | 690 | 940 | 300 MHz | Burst-phase execution |
| Radix-2 minimal resources | 1 | 2 | 540 | 780 | 275 MHz | Minimal footprint |

### 5.5 Detailed Kintex-7 XC7K325T radar-IP resource budget

XC7K325T total capacity: 203,800 CLB LUTs, 407,600 flip-flops, 840 DSP48E1 slices, 445 Block RAM
(36K) tiles (16.0 Mb on-chip RAM). For reference, XC7K410T offers 254,200 LUTs, 508,400 FFs, 1,540
DSPs, 795 BRAM tiles (28.6 Mb).

| Subsystem / IP core | CLB LUTs | FFs | DSP48E1 | BRAM (36K) | On-chip RAM | % LUTs | % DSPs | % BRAM |
|---|---|---|---|---|---|---|---|---|
| RFNoC 4.0 base infrastructure (crossbar, 10GbE MAC, PCIe, radio core) | 42,000 | 68,000 | 40 | 75 | 2.70 Mb | 20.61% | 4.76% | 16.85% |
| FMCW NCO sweep generator (2 ch) | 1,200 | 1,800 | 8 | 4 | 0.14 Mb | 0.59% | 0.95% | 0.90% |
| 5-stage CIC decimator (2 ch) | 2,400 | 3,200 | 8 | 4 | 0.14 Mb | 1.18% | 0.95% | 0.90% |
| Blackman-Harris windowing engine | 400 | 600 | 2 | 2 | 0.07 Mb | 0.20% | 0.24% | 0.45% |
| 1D range FFT (1024-pt pipelined) | 2,360 | 3,700 | 24 | 12 | 0.43 Mb | 1.16% | 2.86% | 2.70% |
| Corner-turning BRAM matrix transpose (dual 512 KB ping-pong) | 1,800 | 2,200 | 0 | 114 | 4.10 Mb | 0.88% | 0.00% | 25.62% |
| 2D Doppler FFT (128-pt pipelined) | 1,400 | 1,900 | 12 | 6 | 0.21 Mb | 0.69% | 1.43% | 1.35% |
| CORDIC beamforming & phase compensation | 1,850 | 2,400 | 0 | 0 | 0.00 Mb | 0.91% | 0.00% | 0.00% |
| TDM GPIO timing sequencer | 350 | 450 | 0 | 0 | 0.00 Mb | 0.17% | 0.00% | 0.00% |
| **Total radar IP subsystem** | **11,760** | **16,250** | **54** | **142** | **5.09 Mb** | **5.77%** | **6.43%** | **31.91%** |
| **Combined system total (RFNoC + radar)** | **53,760** | **84,250** | **94** | **217** | **7.79 Mb** | **26.38%** | **11.19%** | **48.76%** |
| **Surplus unallocated capacity** | **150,040** | **323,350** | **746** | **228** | **8.21 Mb** | **73.62%** | **88.81%** | **51.24%** |

Takeaways: the corner-turn matrix transpose dominates BRAM usage (25.6% alone, to hold a
1024x128 complex ping-pong frame in on-chip RAM with no external DDR3 access). The full radar
acceleration chain uses only 6.4% of DSP slices. The large surplus (74% LUTs, 89% DSPs, 51% BRAM)
comfortably fits onboard 2D CA-CFAR detection and spatial covariance-matrix preprocessing directly
in the FPGA, beyond what's budgeted above.

### 5.6 RTL excerpts
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

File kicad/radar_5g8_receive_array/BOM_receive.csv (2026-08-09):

Ref | Qty | Description | Manufacturer | Part number | Notes
J1-J4 (TX1,TX2,RX1,RX2) | 4 | SMA jack, PCB end launch, solder, 50 ohm, DC-18 GHz | Cinch / Johnson | 142-0701-881 | designed for 0.031 in (0.79 mm) board; this board finishes at 0.850 mm, so the spring legs close on it. Nickel-plated equivalent is 142-0701-886
R1-R4 | 4 | 50.0 ohm +/-1% thin film chip resistor, 0402, to 20 GHz | Vishay | FC0402E50R0BST1 | terminates the hybrid isolated port; a Susumu RR0510P-500-D also fits
D1, D2 | 0 (DO NOT FIT) | Optional receive limiter, 0402, shunt to ground | - | see note | Site is empty as shipped and costs 0.09 dB. Fit ONLY a diode whose total off-state capacitance is 0.10 pF or less: measured in openEMS, 0.1 pF gives -13.8 dB return loss and 0.26 dB loss, 0.2 pF gives -8.1 dB and 0.82 dB, 0.4 pF shorts the line. An in-line coaxial limiter is the alternative if you need more margin
H1-H6 | 6 | M3 mounting hardware | - | - | holes are plated and bonded to the ground plane: use metal hardware if you want the mounting plate grounded, nylon if you do not
PCB | 1 | ZYF300CA-P PTFE, 0.76 mm dielectric, 2 layer, 1 oz, immersion silver (finished 0.850 mm) | PCBWay / JLCPCB | - | 47.237 x 71.368744 mm, see fabrication drawing

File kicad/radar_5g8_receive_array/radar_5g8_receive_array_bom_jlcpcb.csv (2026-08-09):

Comment | Designator | Footprint | LCSC Part #
51R | R3,R4 | R_0402_1005Metric | C25102

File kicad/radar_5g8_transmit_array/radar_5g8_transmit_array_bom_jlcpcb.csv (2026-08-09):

Comment | Designator | Footprint | LCSC Part #
51R | R1,R2 | R_0402_1005Metric | C25102

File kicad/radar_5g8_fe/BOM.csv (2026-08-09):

Ref | Value | Package | Manufacturer part | Note
RAP1 | 150R | 0402
RAP2 | 36R | 0402
RAP3 | 150R | 0402
CA1 | 1n | 0402 | GRM1555C1H102JA01D | blocking capacitor
UA1 | PHA-1H+ | SOT-89 | PHA-1H+ | 0.05-6 GHz driver
CA2 | 1n | 0402 | GRM1555C1H102JA01D | blocking capacitor
UA2 | PMA3-73-1W+ | QFN12 3x3 | PMA3-73-1W+ | the watt; matched to fifty ohms inside the package
CA3 | 1n | 0402 | GRM1555C1H102JA01D | blocking capacitor
RAF | 51R | 0402 |  | loads the forward end of the sampling line
RBP1 | 150R | 0402
RBP2 | 36R | 0402
RBP3 | 150R | 0402
CB1 | 1n | 0402 | GRM1555C1H102JA01D | blocking capacitor
UB1 | PHA-1H+ | SOT-89 | PHA-1H+ | 0.05-6 GHz driver
CB2 | 1n | 0402 | GRM1555C1H102JA01D | blocking capacitor
UB2 | PMA3-73-1W+ | QFN12 3x3 | PMA3-73-1W+ | the watt; matched to fifty ohms inside the package
CB3 | 1n | 0402 | GRM1555C1H102JA01D | blocking capacitor
RBF | 51R | 0402 |  | loads the forward end of the sampling line
CC1 | 100p | 0402 | GRM1555C1H101JA01D | blocking capacitor; the limiter must never see a direct voltage that arrives on the cable
DCL | SMP1330-085LF | QFN 3-pin 2x2 | SMP1330-085LF | invisible until something large arrives
LDCL | 10n | 0402 | 0402HP-10NXGRW | the limiter's return path; the same trick the amplifier's own bias choke uses
CC2 | 100p | 0402 | GRM1555C1H101JA01D | blocking capacitor
UC1 | PMA3-83LN+ | QFN12 3x3 | PMA3-83LN+ | the sensitivity; matched to fifty ohms inside the package
CC3 | 100p | 0402 | GRM1555C1H101JA01D | blocking capacitor
RCP1 | 120R | 0402
RCP2 | 51R | 0402
RCP3 | 120R | 0402
DCC1 | SMS7630-079LF | SOD-523 | SMS7630-079LF | clamps what the radio may see
DCC2 | SMS7630-079LF | SOD-523 | SMS7630-079LF | clamps what the radio may see
CC4 | 100p | 0402 | GRM1555C1H101JA01D | blocking capacitor; nothing direct-current reaches the radio from this board
RCF | 51R | 0402 |  | loads the far end of the sampling line
CD1 | 100p | 0402 | GRM1555C1H101JA01D | blocking capacitor; the limiter must never see a direct voltage that arrives on the cable
DDL | SMP1330-085LF | QFN 3-pin 2x2 | SMP1330-085LF | invisible until something large arrives
LDDL | 10n | 0402 | 0402HP-10NXGRW | the limiter's return path; the same trick the amplifier's own bias choke uses
CD2 | 100p | 0402 | GRM1555C1H101JA01D | blocking capacitor
UD1 | PMA3-83LN+ | QFN12 3x3 | PMA3-83LN+ | the sensitivity; matched to fifty ohms inside the package
CD3 | 100p | 0402 | GRM1555C1H101JA01D | blocking capacitor
RDP1 | 120R | 0402
RDP2 | 51R | 0402
RDP3 | 120R | 0402
DDC1 | SMS7630-079LF | SOD-523 | SMS7630-079LF | clamps what the radio may see
DDC2 | SMS7630-079LF | SOD-523 | SMS7630-079LF | clamps what the radio may see
CD4 | 100p | 0402 | GRM1555C1H101JA01D | blocking capacitor; nothing direct-current reaches the radio from this board
RDF | 51R | 0402 |  | loads the far end of the sampling line
RAS | 0R1 | 2512 |  | reads this side's whole supply current
RAV | 27R | 2512 |  | takes most of the regulator's heat off it
UA3 | AMS1117-5.0 | SOT-223 | AMS1117-5.0 | five volts for this side's driver and receive amplifier
CA5 | 10u | 0805 |  | the regulator's own output capacitor; 16 V part
UA4 | INA181A2IDBVR | SOT-23-6 | INA181A2IDBVR | turns the shunt's sixty millivolts into three volts
CA80 | 100p | 0402 |  | makes the radio-frequency short the quarter-wave feed works against; keep its hole to ground short
CA81 | 1n | 0402
CA82 | 100n | 0402
CA83 | 10u | 1210 |  | 25 V part on the twelve-volt rail
CA90 | 100p | 0402 |  | the same job on the driver's feed
CA91 | 1n | 0402
CA92 | 100n | 0402
CA93 | 10u | 1210
RBS | 0R1 | 2512 |  | reads this side's whole supply current
RBV | 27R | 2512 |  | takes most of the regulator's heat off it
UB3 | AMS1117-5.0 | SOT-223 | AMS1117-5.0 | five volts for this side's driver and receive amplifier
CB5 | 10u | 0805 |  | the regulator's own output capacitor; 16 V part
UB4 | INA181A2IDBVR | SOT-23-6 | INA181A2IDBVR | turns the shunt's sixty millivolts into three volts
CB80 | 100p | 0402 |  | makes the radio-frequency short the quarter-wave feed works against; keep its hole to ground short
CB81 | 1n | 0402
CB82 | 100n | 0402
CB83 | 10u | 1210 |  | 25 V part on the twelve-volt rail
CB90 | 100p | 0402 |  | the same job on the driver's feed
CB91 | 1n | 0402
CB92 | 100n | 0402
CB93 | 10u | 1210
FBC | 600R | 0402 | BLM15HD601SN1 | keeps the transmitter's supply noise out of the receive amplifier
CC80 | 100p | 0402 |  | makes the radio-frequency short the quarter-wave feed works against
CC81 | 1n | 0402
CC82 | 100n | 0402
FBD | 600R | 0402 | BLM15HD601SN1 | keeps the transmitter's supply noise out of the receive amplifier
CD80 | 100p | 0402 |  | makes the radio-frequency short the quarter-wave feed works against
CD81 | 1n | 0402
CD82 | 100n | 0402
J1 | 2-way | 5.08 mm screw terminal |  | twelve volts in, one and a quarter amps
F1 | 1.5 A | 1210 | MF-MSMF150 | resettable fuse
D5 | SMBJ15A | SMB | SMBJ15A | clamps whatever the supply lead picks up
Q3 | AO3401A | SOT-23 | AO3401A | blocks a reversed supply and switches the board
C29 | 22u | 1210
C212 | 22u | 1210
C214 | 100n | 0402
R1 | 100k | 0402 |  | holds the switch on
C1 | 100n | 0402 |  | brings the switch up over ten milliseconds
D6 | 10V | 0402 | BZX84C10 | keeps the transistor's gate inside its rating
Q4 | 2N7002 | SOT-23 | 2N7002 | holds the switch on; the enable line lets go of it
R2 | 100k | 0402 |  | pulls the enable line up if nothing drives it
R3 | 47k | 0402
RAT | 51R | 0402 |  | the sampling line's own load
DA1 | SMS7630 | 0402 | SMS7630-079LF | zero-bias detector diode
CAD0 | 100p | 0402
RAD1 | 10k | 0402
CAD2 | 10n | 0402
RAO | 1k | 0402 |  | keeps the reading off the radio-frequency side
RBT | 51R | 0402 |  | the sampling line's own load
DB1 | SMS7630 | 0402 | SMS7630-079LF | zero-bias detector diode
CBD0 | 100p | 0402
RBD1 | 10k | 0402
CBD2 | 10n | 0402
RBO | 1k | 0402 |  | keeps the reading off the radio-frequency side
RCT | 51R | 0402 |  | the sampling line's own load
DC1 | SMS7630 | 0402 | SMS7630-079LF | zero-bias detector diode
CCD0 | 100p | 0402
RCD1 | 10k | 0402
CCD2 | 10n | 0402
RCO | 1k | 0402 |  | keeps the reading off the radio-frequency side
RDT | 51R | 0402 |  | the sampling line's own load
DD1 | SMS7630 | 0402 | SMS7630-079LF | zero-bias detector diode
CDD0 | 100p | 0402
RDD1 | 10k | 0402
CDD2 | 10n | 0402
RDO | 1k | 0402 |  | keeps the reading off the radio-frequency side
RTA | 10k NTC | 0402 | NCP15XH103F03RC | how hot the board is beside the amplifier
RTB | 10k NTC | 0402 | NCP15XH103F03RC | how hot the board is beside the amplifier
J5 | 8x2 header | 2.54 mm
TX1_RADIO | SMA plug, edge launch | 0.062 in board |  | MALE, the counterpart of the 142-0701-801 used everywhere else on this radar: DC-18 GHz, tab-and-legs end launch for 1.57 mm board, 4.10 mm tab pitch. It screws straight onto the radio's own socket
TX1_ANT | 142-0701-801 | SMA jack end launch | Cinch 142-0701-801 | antenna cable; 0.062 in board
TX2_RADIO | SMA plug, edge launch | 0.062 in board |  | MALE, the counterpart of the 142-0701-801 used everywhere else on this radar: DC-18 GHz, tab-and-legs end launch for 1.57 mm board, 4.10 mm tab pitch. It screws straight onto the radio's own socket
TX2_ANT | 142-0701-801 | SMA jack end launch | Cinch 142-0701-801 | antenna cable; 0.062 in board
RX1_ANT | 142-0701-801 | SMA jack end launch | Cinch 142-0701-801 | antenna cable; 0.062 in board
RX1_RADIO | SMA plug, edge launch | 0.062 in board |  | MALE, the counterpart of the 142-0701-801 used everywhere else on this radar: DC-18 GHz, tab-and-legs end launch for 1.57 mm board, 4.10 mm tab pitch. It screws straight onto the radio's own socket
RX2_ANT | 142-0701-801 | SMA jack end launch | Cinch 142-0701-801 | antenna cable; 0.062 in board
RX2_RADIO | SMA plug, edge launch | 0.062 in board |  | MALE, the counterpart of the 142-0701-801 used everywhere else on this radar: DC-18 GHz, tab-and-legs end launch for 1.57 mm board, 4.10 mm tab pitch. It screws straight onto the radio's own socket
H1-H8 | M3 x 6 pan head and washer | M3 |  | four of the eight sit beside the amplifiers and carry their heat
TIM | thermal pad 0.5 mm, 3 W/mK | 10 x 10 mm |  | under each amplifier, between the bare underside and the chassis

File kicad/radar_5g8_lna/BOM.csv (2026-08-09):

Ref | Value | Package | Manufacturer part | Note
CA1 | 100p | 0402 | GRM1555C1H101JA01D | blocking capacitor; the limiter must not see any direct voltage that arrives on the cable
DAL | SMP1330-085LF | QFN 3-pin 2x2 | SMP1330-085LF | invisible until something large arrives
LDAL | 10n | 0402 | 0402HP-10NXGRW | the limiter's return path; the same trick the amplifier's own bias choke uses
CA2 | 100p | 0402 | GRM1555C1H101JA01D | blocking capacitor
UA1 | PMA3-83LN+ | QFN12 3x3 | PMA3-83LN+ | the sensitivity; matched to fifty ohms inside the package
CA3 | 100p | 0402 | GRM1555C1H101JA01D | blocking capacitor
RAP1 | 120R | 0402
RAP2 | 51R | 0402
RAP3 | 120R | 0402
DAC1 | SMS7630-079LF | SOD-523 | SMS7630-079LF | clamps what the radio may see
DAC2 | SMS7630-079LF | SOD-523 | SMS7630-079LF | clamps what the radio may see
CA4 | 100p | 0402 | GRM1555C1H101JA01D | blocking capacitor; nothing direct-current reaches the radio from this board
RAJ | 51R | 0402 |  | terminates the injection port; REMOVE IT when a canceller goes on that connector
CB1 | 100p | 0402 | GRM1555C1H101JA01D | blocking capacitor; the limiter must not see any direct voltage that arrives on the cable
DBL | SMP1330-085LF | QFN 3-pin 2x2 | SMP1330-085LF | invisible until something large arrives
LDBL | 10n | 0402 | 0402HP-10NXGRW | the limiter's return path; the same trick the amplifier's own bias choke uses
CB2 | 100p | 0402 | GRM1555C1H101JA01D | blocking capacitor
UB1 | PMA3-83LN+ | QFN12 3x3 | PMA3-83LN+ | the sensitivity; matched to fifty ohms inside the package
CB3 | 100p | 0402 | GRM1555C1H101JA01D | blocking capacitor
RBP1 | 120R | 0402
RBP2 | 51R | 0402
RBP3 | 120R | 0402
DBC1 | SMS7630-079LF | SOD-523 | SMS7630-079LF | clamps what the radio may see
DBC2 | SMS7630-079LF | SOD-523 | SMS7630-079LF | clamps what the radio may see
CB4 | 100p | 0402 | GRM1555C1H101JA01D | blocking capacitor; nothing direct-current reaches the radio from this board
RBJ | 51R | 0402 |  | terminates the injection port; REMOVE IT when a canceller goes on that connector
RAS | 1R0 | 2512 |  | reads the amplifier's supply current
RAV | 82R | 2512 |  | takes most of the regulator's heat off it
UA2 | AMS1117-5.0 | SOT-223 | AMS1117-5.0 | five volts, the same regulator the transmit board uses
CA5 | 10u | 0805
UA3 | INA181A2IDBVR | SOT-23-6 | INA181A2IDBVR | turns the shunt's sixty millivolts into three volts
CA6 | 10u | 1210
CA7 | 100n | 0402
CA80 | 100p | 0402 |  | makes the radio-frequency short the quarter-wave feed works against
CA81 | 1n | 0402
CA82 | 100n | 0402
CA83 | 10u | 1210
RBS | 1R0 | 2512 |  | reads the amplifier's supply current
RBV | 82R | 2512 |  | takes most of the regulator's heat off it
UB2 | AMS1117-5.0 | SOT-223 | AMS1117-5.0 | five volts, the same regulator the transmit board uses
CB5 | 10u | 0805
UB3 | INA181A2IDBVR | SOT-23-6 | INA181A2IDBVR | turns the shunt's sixty millivolts into three volts
CB6 | 10u | 1210
CB7 | 100n | 0402
CB80 | 100p | 0402 |  | makes the radio-frequency short the quarter-wave feed works against
CB81 | 1n | 0402
CB82 | 100n | 0402
CB83 | 10u | 1210
J5 | 2x7 header | 2.54 mm
J1 | 2-way | 5.08 mm screw terminal |  | twelve volts in, a quarter of an amp
F1 | 1.0 A | 1210 | MF-MSMF100 | resettable fuse
D5 | SMBJ15A | SMB | SMBJ15A | clamps whatever the supply lead picks up
Q3 | AO3401A | SOT-23 | AO3401A | blocks a reversed supply and switches the board
C20 | 22u | 1210
C21 | 100n | 0402
R1 | 100k | 0402 |  | holds the switch on
C1 | 100n | 0402 |  | brings the switch up over ten milliseconds
D6 | 10V | 0402 | BZX84C10 | keeps the transistor's gate inside its rating
Q4 | 2N7002 | SOT-23 | 2N7002 | holds the switch on; the enable line lets go of it
R2 | 100k | 0402
R3 | 47k | 0402
RAT | 51R | 0402 |  | the sampling line's own load
DA1 | SMS7630 | 0402 | SMS7630-079LF | zero-bias detector diode
CAD0 | 100p | 0402
RAD1 | 10k | 0402
CAD2 | 10n | 0402
RAO | 1k | 0402 |  | keeps the reading off the radio-frequency side
RBT | 51R | 0402 |  | the sampling line's own load
DB1 | SMS7630 | 0402 | SMS7630-079LF | zero-bias detector diode
CBD0 | 100p | 0402
RBD1 | 10k | 0402
CBD2 | 10n | 0402
RBO | 1k | 0402 |  | keeps the reading off the radio-frequency side
RTA | 10k NTC | 0402 | NCP15XH103F03RC | how hot the board is beside the amplifier
RTB | 10k NTC | 0402 | NCP15XH103F03RC | how hot the board is beside the amplifier
RX1_IN | 142-0701-801 | SMA end launch | Cinch 142-0701-801 | left edge, 0.062 in board
RX1_OUT | 142-0701-801 | SMA end launch | Cinch 142-0701-801 | right edge, 0.062 in board
RX1_INJ | 142-0701-801 | SMA end launch | Cinch 142-0701-801 | top edge, 0.062 in board
RX2_IN | 142-0701-801 | SMA end launch | Cinch 142-0701-801 | left edge, 0.062 in board
RX2_OUT | 142-0701-801 | SMA end launch | Cinch 142-0701-801 | right edge, 0.062 in board
RX2_INJ | 142-0701-801 | SMA end launch | Cinch 142-0701-801 | bottom edge, 0.062 in board
H1-H6 | M3 x 6 pan head and washer | M3 |  | the two middle ones sit beside the amplifiers
TIM | thermal pad 0.5 mm, 3 W/mK | 10 x 10 mm |  | under each amplifier, between the bare underside and the chassis

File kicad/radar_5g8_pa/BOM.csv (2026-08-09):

Ref | Value | Package | Manufacturer part | Note
RAP1 | 150R | 0402
RAP2 | 36R | 0402
RAP3 | 150R | 0402
CA1 | 1n | 0402 | GRM1555C1H102JA01D | blocking capacitor
UA1 | PHA-1H+ | SOT-89 | PHA-1H+ | 0.05-6 GHz driver
CA2 | 1n | 0402 | GRM1555C1H102JA01D | blocking capacitor
UA2 | PMA3-73-1W+ | QFN12 3x3 | PMA3-73-1W+ | the watt; matched to fifty ohms inside the package
CA3 | 1n | 0402 | GRM1555C1H102JA01D | blocking capacitor
RAF | 51R | 0402 |  | terminates the sample port; REMOVE IT when a cable goes on that connector
RBP1 | 150R | 0402
RBP2 | 36R | 0402
RBP3 | 150R | 0402
CB1 | 1n | 0402 | GRM1555C1H102JA01D | blocking capacitor
UB1 | PHA-1H+ | SOT-89 | PHA-1H+ | 0.05-6 GHz driver
CB2 | 1n | 0402 | GRM1555C1H102JA01D | blocking capacitor
UB2 | PMA3-73-1W+ | QFN12 3x3 | PMA3-73-1W+ | the watt; matched to fifty ohms inside the package
CB3 | 1n | 0402 | GRM1555C1H102JA01D | blocking capacitor
RBF | 51R | 0402 |  | terminates the sample port; REMOVE IT when a cable goes on that connector
RAS | 0R1 | 2512 |  | reads the final amplifier's supply current
RAV | 27R | 2512 |  | takes most of the regulator's heat off it
UA3 | AMS1117-5.0 | SOT-223 | AMS1117-5.0 | five volts for the driver
CA5 | 10u | 0805 |  | 16 V part; ten microfarads does not come in an 0402
UA4 | INA181A2IDBVR | SOT-23-6 | INA181A2IDBVR | turns the shunt's forty millivolts into two volts
CA6 | 10u | 1210
CA7 | 100n | 0402
CA80 | 100p | 0402 |  | makes the radio-frequency short the quarter-wave feed works against; keep its ground via short
CA81 | 1n | 0402
CA82 | 100n | 0402
CA83 | 10u | 1210 |  | 25 V part on the twelve-volt rail
CA90 | 100p | 0402 |  | the same job on the driver's feed
CA91 | 1n | 0402
CA92 | 100n | 0402
CA93 | 10u | 1210
RBS | 0R1 | 2512 |  | reads the final amplifier's supply current
RBV | 27R | 2512 |  | takes most of the regulator's heat off it
UB3 | AMS1117-5.0 | SOT-223 | AMS1117-5.0 | five volts for the driver
CB5 | 10u | 0805 |  | 16 V part; ten microfarads does not come in an 0402
UB4 | INA181A2IDBVR | SOT-23-6 | INA181A2IDBVR | turns the shunt's forty millivolts into two volts
CB6 | 10u | 1210
CB7 | 100n | 0402
CB80 | 100p | 0402 |  | makes the radio-frequency short the quarter-wave feed works against; keep its ground via short
CB81 | 1n | 0402
CB82 | 100n | 0402
CB83 | 10u | 1210 |  | 25 V part on the twelve-volt rail
CB90 | 100p | 0402 |  | the same job on the driver's feed
CB91 | 1n | 0402
CB92 | 100n | 0402
CB93 | 10u | 1210
J5 | 2x7 header | 2.54 mm
J1 | 2-way | 5.08 mm screw terminal |  | twelve volts in, one and a quarter amps
F1 | 1.5 A | 1210 | MF-MSMF150 | resettable fuse
D5 | SMBJ15A | SMB | SMBJ15A | clamps whatever the supply lead picks up
Q3 | AO3401A | SOT-23 | AO3401A | blocks a reversed supply and switches the board
C20 | 22u | 1210
C21 | 22u | 1210
C22 | 100n | 0402
R1 | 100k | 0402 |  | holds the switch on
C1 | 100n | 0402 |  | brings the switch up over ten milliseconds
D6 | 10V | 0402 | BZX84C10 | keeps the transistor's gate inside its rating
Q4 | 2N7002 | SOT-23 | 2N7002 | holds the switch on; the enable line lets go of it
R2 | 100k | 0402
R3 | 47k | 0402
RAT | 51R | 0402 |  | the sampling line's own load; without it the coupler is a pair of reflections
DA1 | SMS7630 | 0402 | SMS7630-079LF | zero-bias detector diode
CAD0 | 100p | 0402
RAD1 | 10k | 0402
CAD2 | 10n | 0402
RAO | 1k | 0402 |  | keeps the reading off the radio-frequency side
RBT | 51R | 0402 |  | the sampling line's own load; without it the coupler is a pair of reflections
DB1 | SMS7630 | 0402 | SMS7630-079LF | zero-bias detector diode
CBD0 | 100p | 0402
RBD1 | 10k | 0402
CBD2 | 10n | 0402
RBO | 1k | 0402 |  | keeps the reading off the radio-frequency side
RTA | 10k NTC | 0402 | NCP15XH103F03RC | how hot the board is beside the amplifier
RTB | 10k NTC | 0402 | NCP15XH103F03RC | how hot the board is beside the amplifier
TX1_IN | 142-0701-801 | SMA end launch | Cinch 142-0701-801 | left edge, 0.062 in board
TX1_OUT | 142-0701-801 | SMA end launch | Cinch 142-0701-801 | right edge, 0.062 in board
TX1_FWD | 142-0701-801 | SMA end launch | Cinch 142-0701-801 | right edge, 0.062 in board
TX2_IN | 142-0701-801 | SMA end launch | Cinch 142-0701-801 | left edge, 0.062 in board
TX2_OUT | 142-0701-801 | SMA end launch | Cinch 142-0701-801 | right edge, 0.062 in board
TX2_FWD | 142-0701-801 | SMA end launch | Cinch 142-0701-801 | right edge, 0.062 in board
H1-H6 | M3 x 6 pan head and washer | M3 |  | two of the six sit beside the amplifiers and carry their heat
TIM | thermal pad 0.5 mm, 3 W/mK | 10 x 10 mm |  | under each amplifier, between the bare underside and the chassis

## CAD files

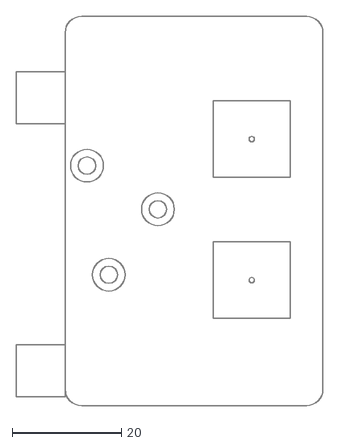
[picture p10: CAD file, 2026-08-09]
kicad/radar_5g8_receive_array/radar_5g8_receive_array_MECHANICAL.dxf
56.2 x 71.4

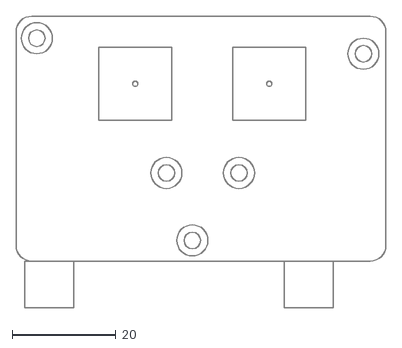
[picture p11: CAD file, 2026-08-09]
kicad/radar_5g8_transmit_array/radar_5g8_transmit_array_MECHANICAL.dxf
71.3 x 56.2

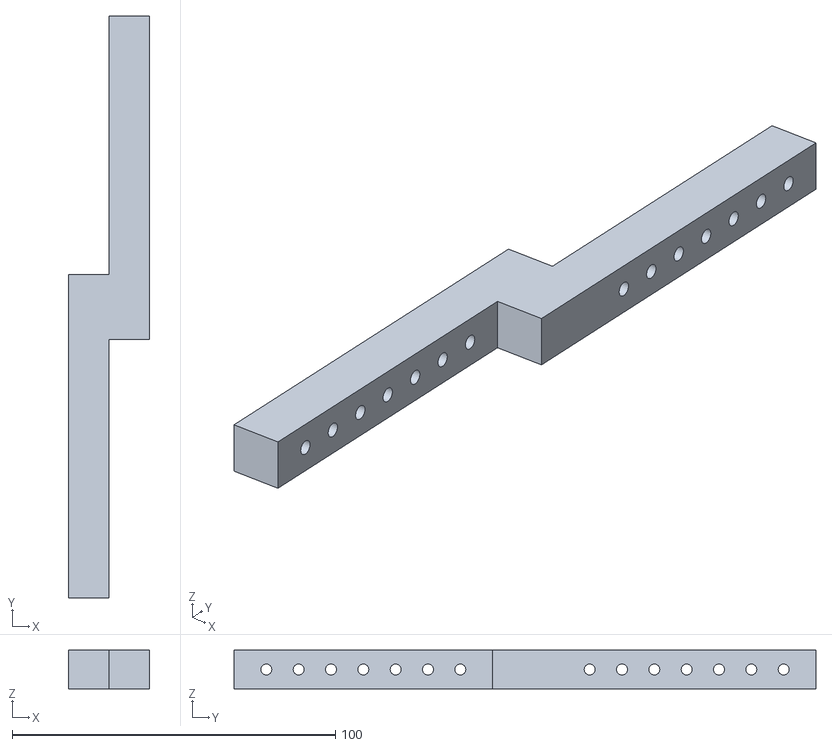
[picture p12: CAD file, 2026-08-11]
mech/extender.stl
25.0 x 180.0 x 12.0

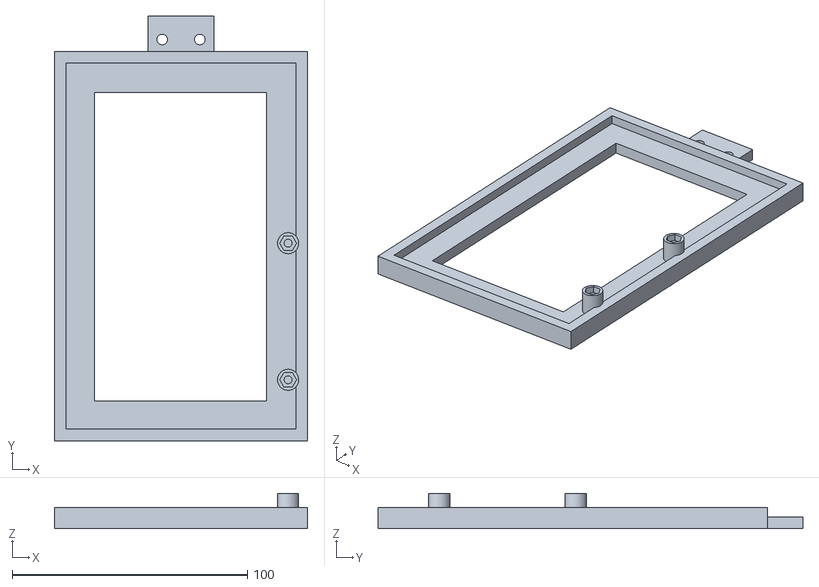
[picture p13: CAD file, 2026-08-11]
mech/cradle.stl
107.5 x 180.5 x 15.0

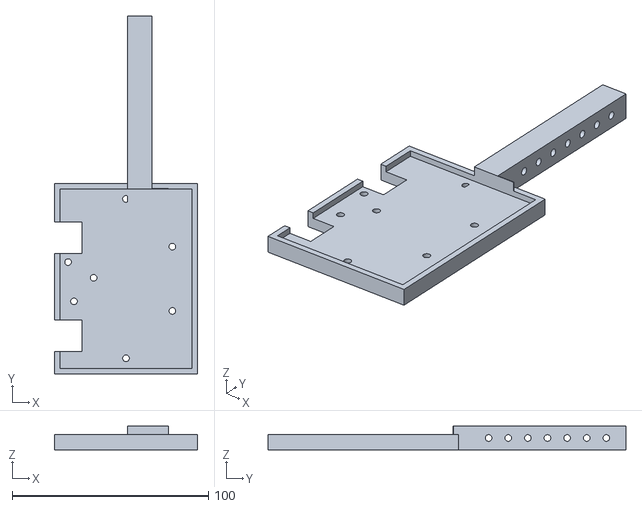
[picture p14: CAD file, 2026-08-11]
mech/half_receive.stl
73.0 x 182.4 x 12.0

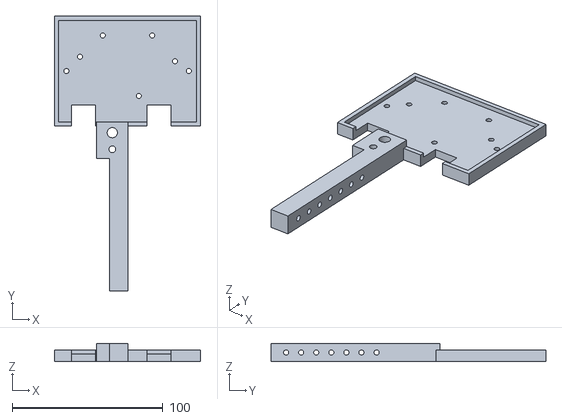
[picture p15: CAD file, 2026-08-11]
mech/half_transmit.stl
97.0 x 182.4 x 12.0

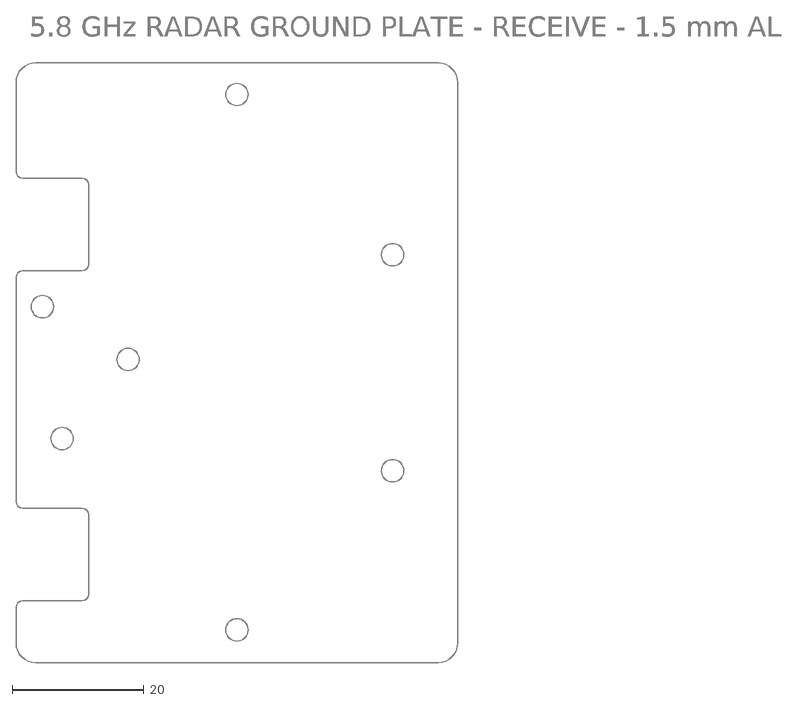
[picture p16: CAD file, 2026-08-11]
mech/plate_receive.dxf
5.8 GHz RADAR GROUND PLATE - RECEIVE - 1.5 mm AL

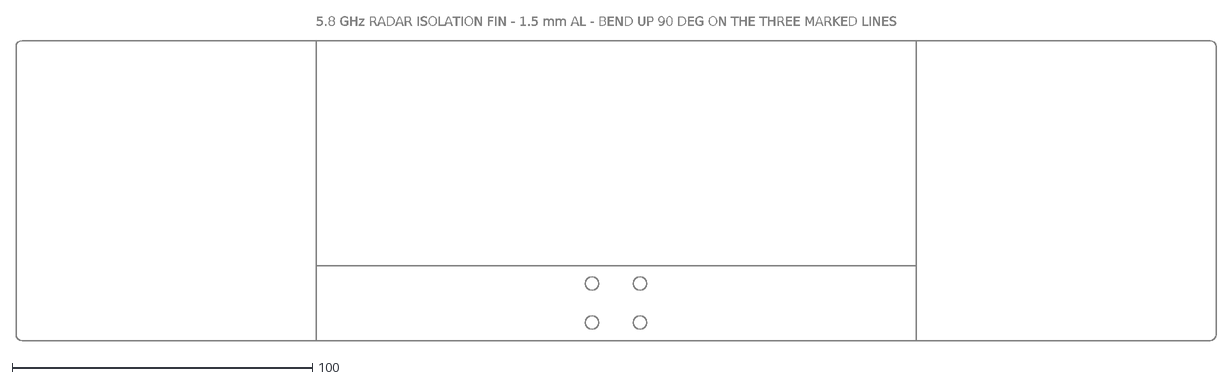
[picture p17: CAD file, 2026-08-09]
mech/fin.dxf
5.8 GHz RADAR ISOLATION FIN - 1.5 mm AL - BEND UP 90 DEG ON THE THREE MARKED LINES

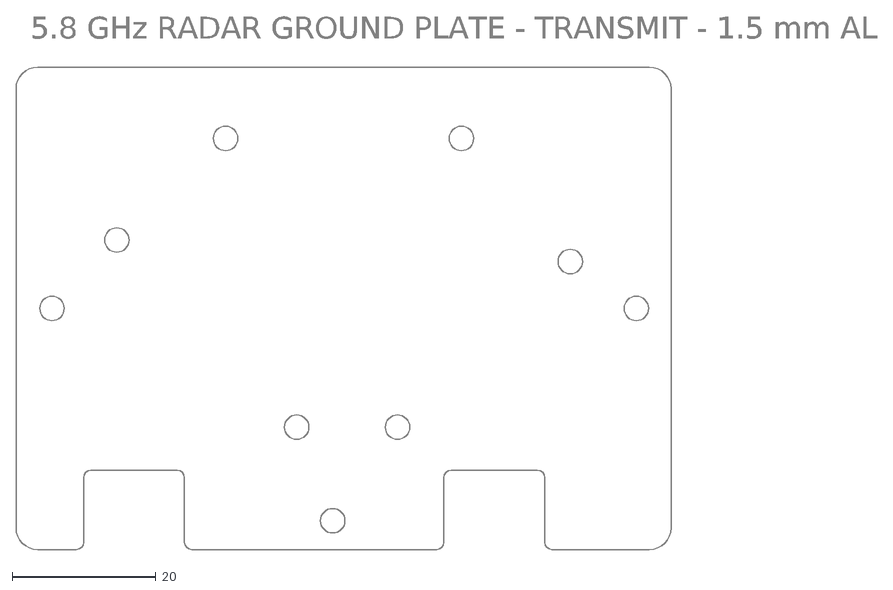
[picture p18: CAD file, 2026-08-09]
mech/plate_transmit.dxf
5.8 GHz RADAR GROUND PLATE - TRANSMIT - 1.5 mm AL

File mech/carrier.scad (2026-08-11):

// GENERATED by carrier.py -- edit that, not this.
//
// Two printed halves.  Each carries one array on a 1.5 mm aluminium plate,
// and they bolt to each other through the lap in the middle of the bar.
// Print both flat, opening upwards, no supports.
//
//   separation is set by which holes you line up in the lap:
//   370 to 430 mm in 10 mm steps.  400 is the design point.

part = "all";     // "transmit" | "receive" | "all"
$fn = 48;

module tray_tx() {
  difference() {
    union() {
      translate([-48.921, -37.195, 0])
        cube([97.000, 73.000, 7.70]);
    }
    // pocket the plate drops into
    translate([-46.071, -34.345, 5.00])
      cube([91.300, 67.300, 3.70]);
    // fasteners, each with an M3 nut trapped in the underside
      translate([-31.921, 8.805, -1]) cylinder(d=7.159, h=3.80, $fn=6);
      translate([-31.921, 8.805, -1]) cylinder(d=3.40, h=8.00);
      translate([31.079, 5.805, -1]) cylinder(d=7.159, h=3.80, $fn=6);
      translate([31.079, 5.805, -1]) cylinder(d=3.40, h=8.00);
      translate([-1.921, -30.195, -1]) cylinder(d=7.159, h=3.80, $fn=6);
      translate([-1.921, -30.195, -1]) cylinder(d=3.40, h=8.00);
      translate([7.079, -17.195, -1]) cylinder(d=7.159, h=3.80, $fn=6);
      translate([7.079, -17.195, -1]) cylinder(d=3.40, h=8.00);
      translate([-6.921, -17.195, -1]) cylinder(d=7.159, h=3.80, $fn=6);
      translate([-6.921, -17.195, -1]) cylinder(d=3.40, h=8.00);
      translate([-40.921, -0.695, -1]) cylinder(d=7.159, h=3.80, $fn=6);
      translate([-40.921, -0.695, -1]) cylinder(d=3.40, h=8.00);
      translate([40.250, -0.695, -1]) cylinder(d=7.159, h=3.80, $fn=6);
      translate([40.250, -0.695, -1]) cylinder(d=3.40, h=8.00);
      translate([-16.801, 22.923, -1]) cylinder(d=7.159, h=3.80, $fn=6);
      translate([-16.801, 22.923, -1]) cylinder(d=3.40, h=8.00);
      translate([15.959, 22.923, -1]) cylinder(d=7.159, h=3.80, $fn=6);
      translate([15.959, 22.923, -1]) cylinder(d=3.40, h=8.00);
  }
}

module tray_rx() {
  difference() {
    union() {
      translate([-37.195, -448.948, 0])
        cube([73.000, 97.000, 7.70]);
    }
    // pocket the plate drops into
    translate([-34.345, -446.098, 5.00])
      cube([67.300, 91.300, 3.70]);
    // fasteners, each with an M3 nut trapped in the underside
      translate([-30.195, -391.948, -1]) cylinder(d=7.159, h=3.80, $fn=6);
      translate([-30.195, -391.948, -1]) cylinder(d=3.40, h=8.00);
      translate([-27.195, -411.948, -1]) cylinder(d=7.159, h=3.80, $fn=6);
      translate([-27.195, -411.948, -1]) cylinder(d=3.40, h=8.00);
      translate([-17.195, -399.948, -1]) cylinder(d=7.159, h=3.80, $fn=6);
      translate([-17.195, -399.948, -1]) cylinder(d=3.40, h=8.00);
      translate([-0.695, -440.948, -1]) cylinder(d=7.159, h=3.80, $fn=6);
      translate([-0.695, -440.948, -1]) cylinder(d=3.40, h=8.00);
      translate([-0.695, -359.763, -1]) cylinder(d=7.159, h=3.80, $fn=6);
      translate([-0.695, -359.763, -1]) cylinder(d=3.40, h=8.00);
      translate([22.923, -416.828, -1]) cylinder(d=7.159, h=3.80, $fn=6);
      translate([22.923, -416.828, -1]) cylinder(d=3.40, h=8.00);
      translate([22.923, -384.068, -1]) cylinder(d=7.159, h=3.80, $fn=6);
      translate([22.923, -384.068, -1]) cylinder(d=3.40, h=8.00);
  }
}

module arm_tx() {{
  difference() {{
    union() {{
      translate([-12.500, -146.571, 0])
        cube([12.500, 143.376, 12.00]);
      // local pad, deep enough to swallow a 1/4-20 tripod nut
      translate([-21.000, -58.571, 0])
        cube([8.50, 34.00, 12.00]);
    }}
    translate([-13.500, -136.571, 6.00]) rotate([0,90,0]) cylinder(d=3.40, h=27.00, $fn=24);
    translate([-13.500, -126.571, 6.00]) rotate([0,90,0]) cylinder(d=3.40, h=27.00, $fn=24);
    translate([-13.500, -116.571, 6.00]) rotate([0,90,0]) cylinder(d=3.40, h=27.00, $fn=24);
    translate([-13.500, -106.571, 6.00]) rotate([0,90,0]) cylinder(d=3.40, h=27.00, $fn=24);
    translate([-13.500, -96.571, 6.00]) rotate([0,90,0]) cylinder(d=3.40, h=27.00, $fn=24);
    translate([-13.500, -86.571, 6.00]) rotate([0,90,0]) cylinder(d=3.40, h=27.00, $fn=24);
    translate([-13.500, -76.571, 6.00]) rotate([0,90,0]) cylinder(d=3.40, h=27.00, $fn=24);
    // tripod thread, and two M4 for any flat bracket
    translate([-10.500, -41.571, -1])
      cylinder(d=6.80, h=14.00, $fn=32);
    translate([-10.500, -41.571, -0.01])
      cylinder(d=13.164, h=6.00, $fn=6);
    translate([-10.500, -52.571, -1])
      cylinder(d=4.5, h=14.00, $fn=24);
    translate([-10.500, -30.571, -1])
      cylinder(d=4.5, h=14.00, $fn=24);
  }}
}}

module arm_rx() {{
  difference() {{
    union() {{
      translate([0.000, -385.948, 0])
        cube([12.500, 119.376, 12.00]);
      // local pad, deep enough to swallow a 1/4-20 tripod nut
      translate([12.500, -388.571, 0])
        cube([8.50, 34.00, 12.00]);
    }}
    translate([-13.500, -276.571, 6.00]) rotate([0,90,0]) cylinder(d=3.40, h=27.00, $fn=24);
    translate([-13.500, -286.571, 6.00]) rotate([0,90,0]) cylinder(d=3.40, h=27.00, $fn=24);
    translate([-13.500, -296.571, 6.00]) rotate([0,90,0]) cylinder(d=3.40, h=27.00, $fn=24);
    translate([-13.500, -306.571, 6.00]) rotate([0,90,0]) cylinder(d=3.40, h=27.00, $fn=24);
    translate([-13.500, -316.571, 6.00]) rotate([0,90,0]) cylinder(d=3.40, h=27.00, $fn=24);
    translate([-13.500, -326.571, 6.00]) rotate([0,90,0]) cylinder(d=3.40, h=27.00, $fn=24);
    translate([-13.500, -336.571, 6.00]) rotate([0,90,0]) cylinder(d=3.40, h=27.00, $fn=24);
    // tripod thread, and two M4 for any flat bracket
    translate([10.500, -371.571, -1])
      cylinder(d=6.80, h=14.00, $fn=32);
    translate([10.500, -371.571, -0.01])
      cylinder(d=13.164, h=6.00, $fn=6);
    translate([10.500, -382.571, -1])
      cylinder(d=4.5, h=14.00, $fn=24);
    translate([10.500, -360.571, -1])
      cylinder(d=4.5, h=14.00, $fn=24);
  }}
}}

module half_tx() {
  difference() {
    union() {
      tray_tx();
      arm_tx();
    }
    // The arm reaches 34 mm back under its own tray, so the pocket has
    // to be cut a second time from the finished union.  It must also be cut
    // ALL the way up: the arm is 12 mm thick against the tray's
    // 7.7 mm, and a pocket only as deep as the plate left a
    // tongue of plastic hanging over the antenna's face, 1.4 mm off the
    // copper.  Nothing may stand in front of a patch.
    translate([-46.071, -34.345, 5.00])
      cube([91.300, 67.300, 17.00]);
    // clear runs for the coaxial connectors
    translate([-37.521, -48.195, -1]) cube([16.000, 25.000, 14.00]);
    translate([12.523, -48.195, -1]) cube([16.000, 25.000, 14.00]);
  }
}

module half_rx() {
  difference() {
    union() {
      tray_rx();
      arm_rx();
    }
    translate([-34.345, -446.098, 5.00])
      cube([67.300, 91.300, 17.00]);
    translate([-51.195, -437.521, -1]) cube([28.000, 16.000, 14.00]);
    translate([-51.195, -387.477, -1]) cube([28.000, 16.000, 14.00]);
  }
}


module cradle() {
  difference() {
    union() {
      cube([107.50, 165.50, 9.00]);
      // two tabs onto the spine's own mounting pad
      translate([39.75, 164.50, 0])
        cube([28.0, 16.0, 5.00]);
    }
    // the radio drops in from the front
    translate([5.00, 5.00, 5.00])
      cube([97.50, 155.50, 5.00]);
    // and most of the back is open, so it can breathe and lose weight
    translate([17.00, 17.00, -1])
      cube([73.00, 131.00, 7.00]);
    // four M4 onto the spine pad
    for (dx = [-8, 8], dy = [6, 19])
      translate([53.75 + dx, 165.50 + dy - 1, -1])
        cylinder(d=4.50, h=7.00, $fn=24);
  }
  // posts holding the outer edge of the front-end board
  for (p = [21.0, 79.0])
    translate([53.75 - 50.0 + 100.0 - 4.5, p + 5.00, 0])
      difference() {
        cylinder(d=9.0, h=15.00, $fn=32);
        translate([0, 0, 12.00])
          cylinder(d=7.159, h=3.80, $fn=6);
        translate([0, 0, -1]) cylinder(d=3.40, h=17.00);
      }
}
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

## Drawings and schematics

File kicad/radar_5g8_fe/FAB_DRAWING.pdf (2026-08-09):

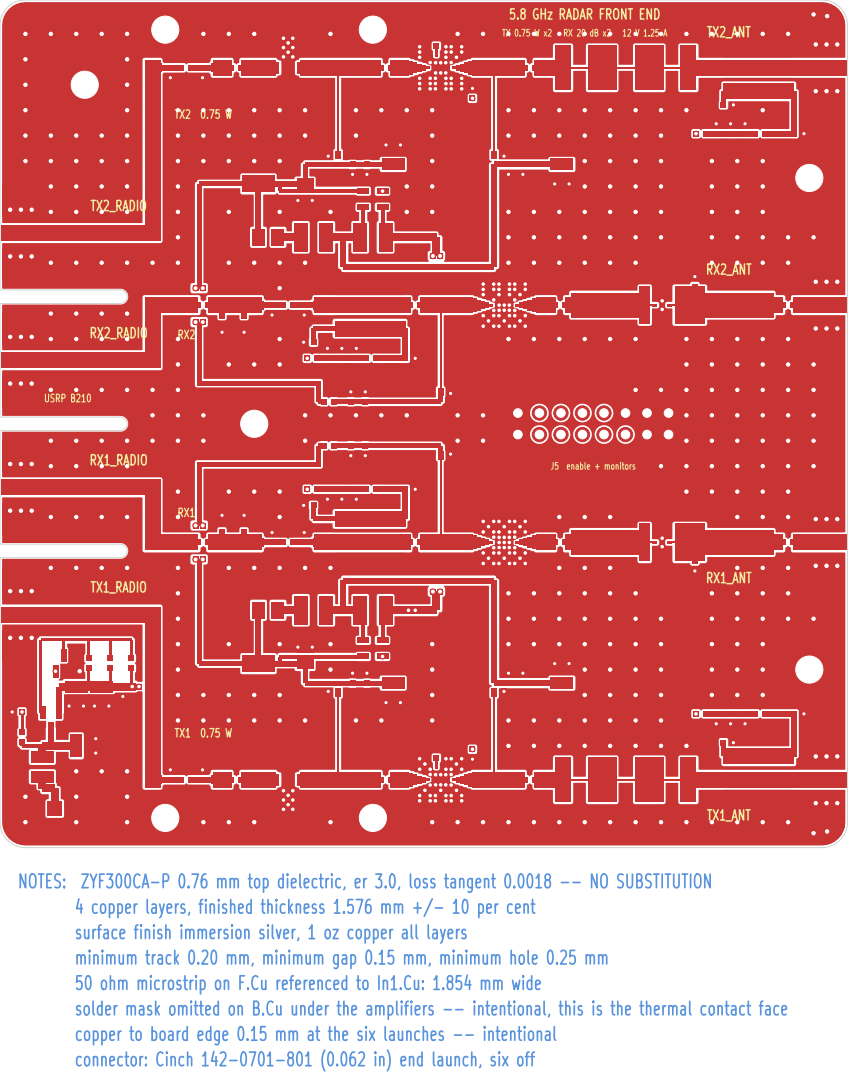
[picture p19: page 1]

5.8 GHz RADAR FRONT END

NOTES: ZYF300CA-P 0.76 mm top dielectric, er 3.0, loss tangent 0.0018 -- NO SUBSTITUTION
4 copper layers, finished thickness 1.576 mm +/- 10 per cent
surface finish immersion silver, 1 oz copper all layers
minimum track 0.20 mm, minimum gap 0.15 mm, minimum hole 0.25 mm
50 ohm microstrip on F.Cu referenced to In1.Cu: 1.854 mm wide
solder mask omitted on B.Cu under the amplifiers -- intentional, this is the thermal contact face
copper to board edge 0.15 mm at the six launches -- intentional
connector: Cinch 142-0701-801 (0.062 in) end launch, six off

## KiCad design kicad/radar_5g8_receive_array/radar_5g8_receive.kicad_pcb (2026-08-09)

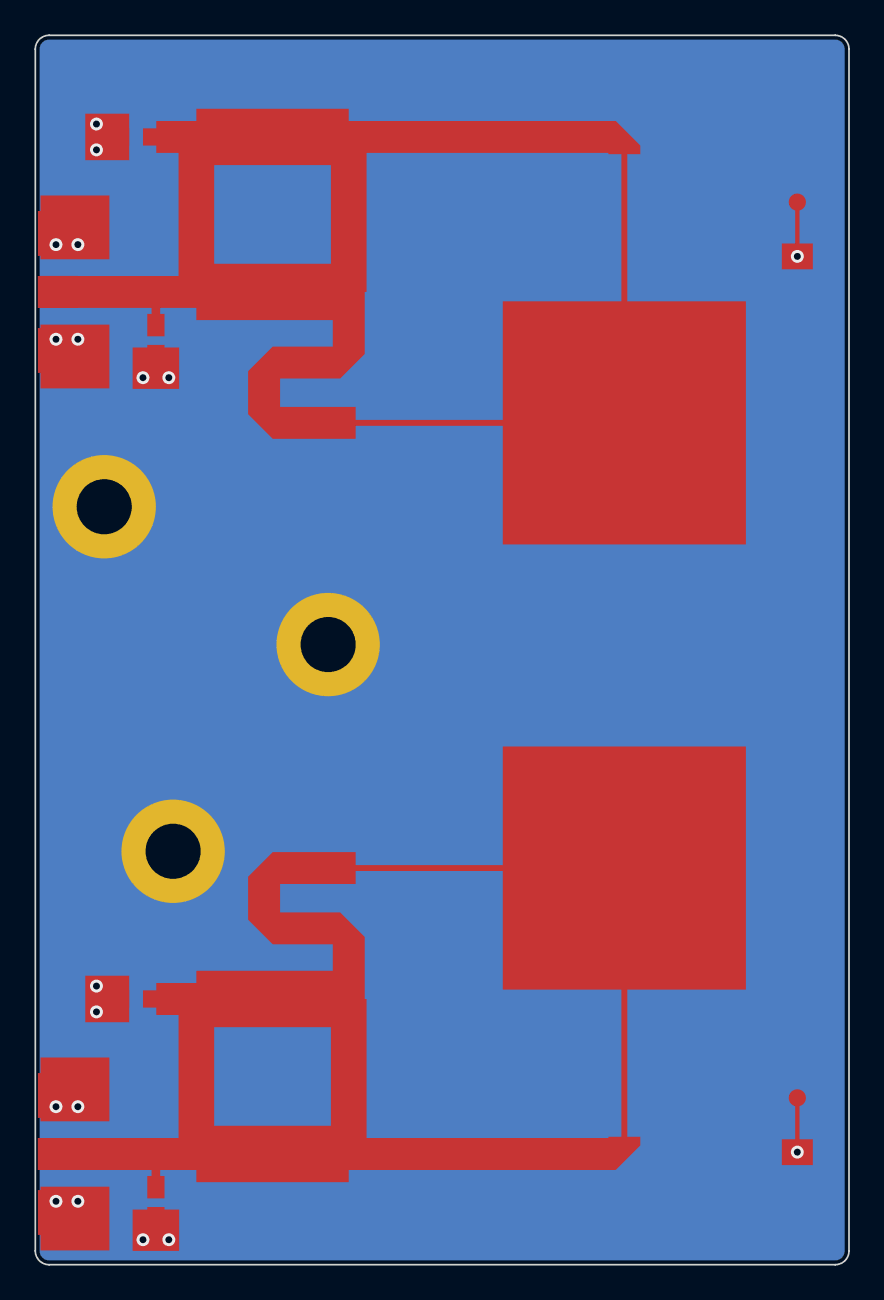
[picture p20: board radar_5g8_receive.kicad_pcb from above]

Board: 2 copper layers, 47.2 x 71.4 mm, 9 parts (0 on the bottom side), 3 nets, no tracks yet.

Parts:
D1, D2: DNF - limiter site; D_0805_Limiter
H1, H2, H3: M3; MountingHole_M3
R3, R4: 50R; R_0805_1W_50R
RX1, RX2: SMA-EDGE-50R; SMA_EndLaunch_50R_LeftEdge

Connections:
GND: D1.2, D2.2, H1.1, H2.1, H3.1, R3.2, R4.2, RX1.2, RX1.3, RX2.2, RX2.3
RX1: D1.1, R3.1, RX1.1
RX2: D2.1, R4.1, RX2.1

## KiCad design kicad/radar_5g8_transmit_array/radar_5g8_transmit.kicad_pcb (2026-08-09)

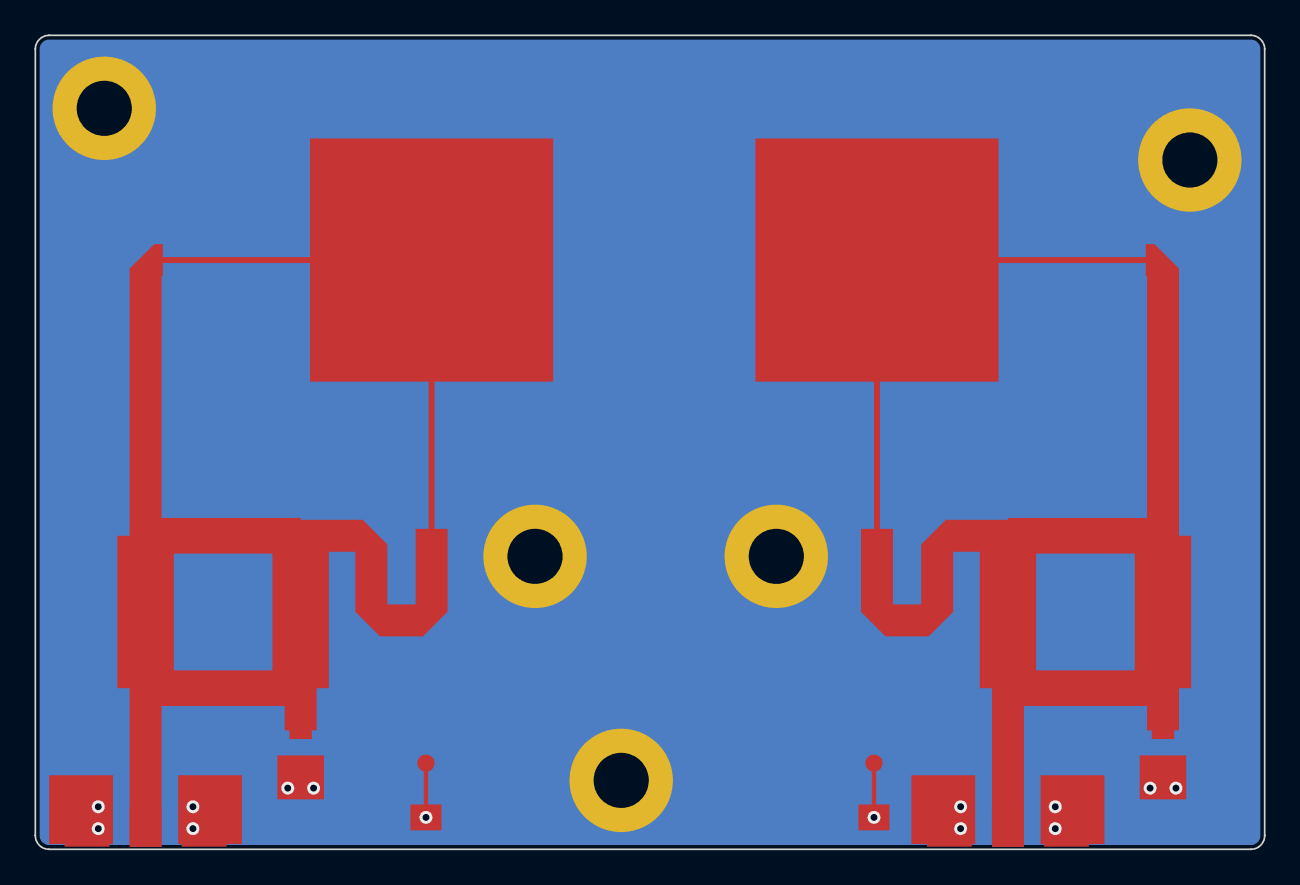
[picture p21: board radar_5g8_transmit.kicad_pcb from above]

Board: 2 copper layers, 71.3 x 47.2 mm, 9 parts (0 on the bottom side), 3 nets, no tracks yet.

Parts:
H1, H2, H3, H4, H5: M3; MountingHole_M3
R1, R2: 50R; R_0805_1W_50R
TX1, TX2: SMA-EDGE-50R; SMA_EndLaunch_50R_BottomEdge

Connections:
GND: H1.1, H2.1, H3.1, H4.1, H5.1, R1.2, R2.2, TX1.2, TX1.3, TX2.2, TX2.3
TX1: R1.1, TX1.1
TX2: R2.1, TX2.1

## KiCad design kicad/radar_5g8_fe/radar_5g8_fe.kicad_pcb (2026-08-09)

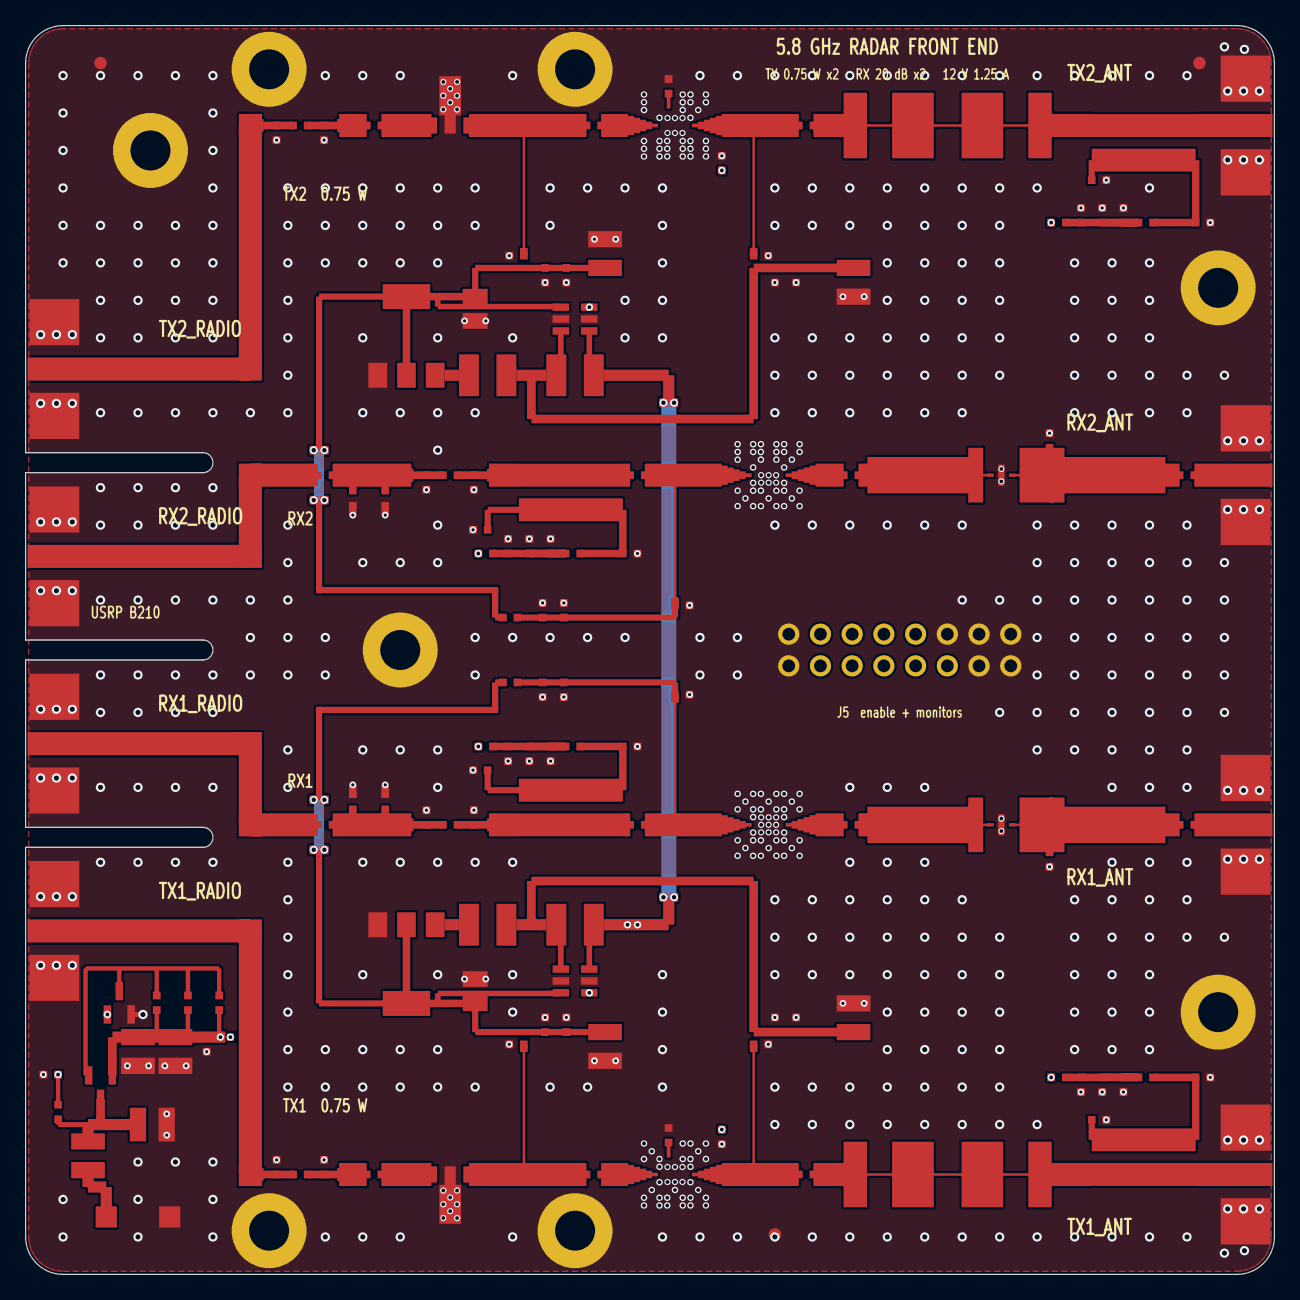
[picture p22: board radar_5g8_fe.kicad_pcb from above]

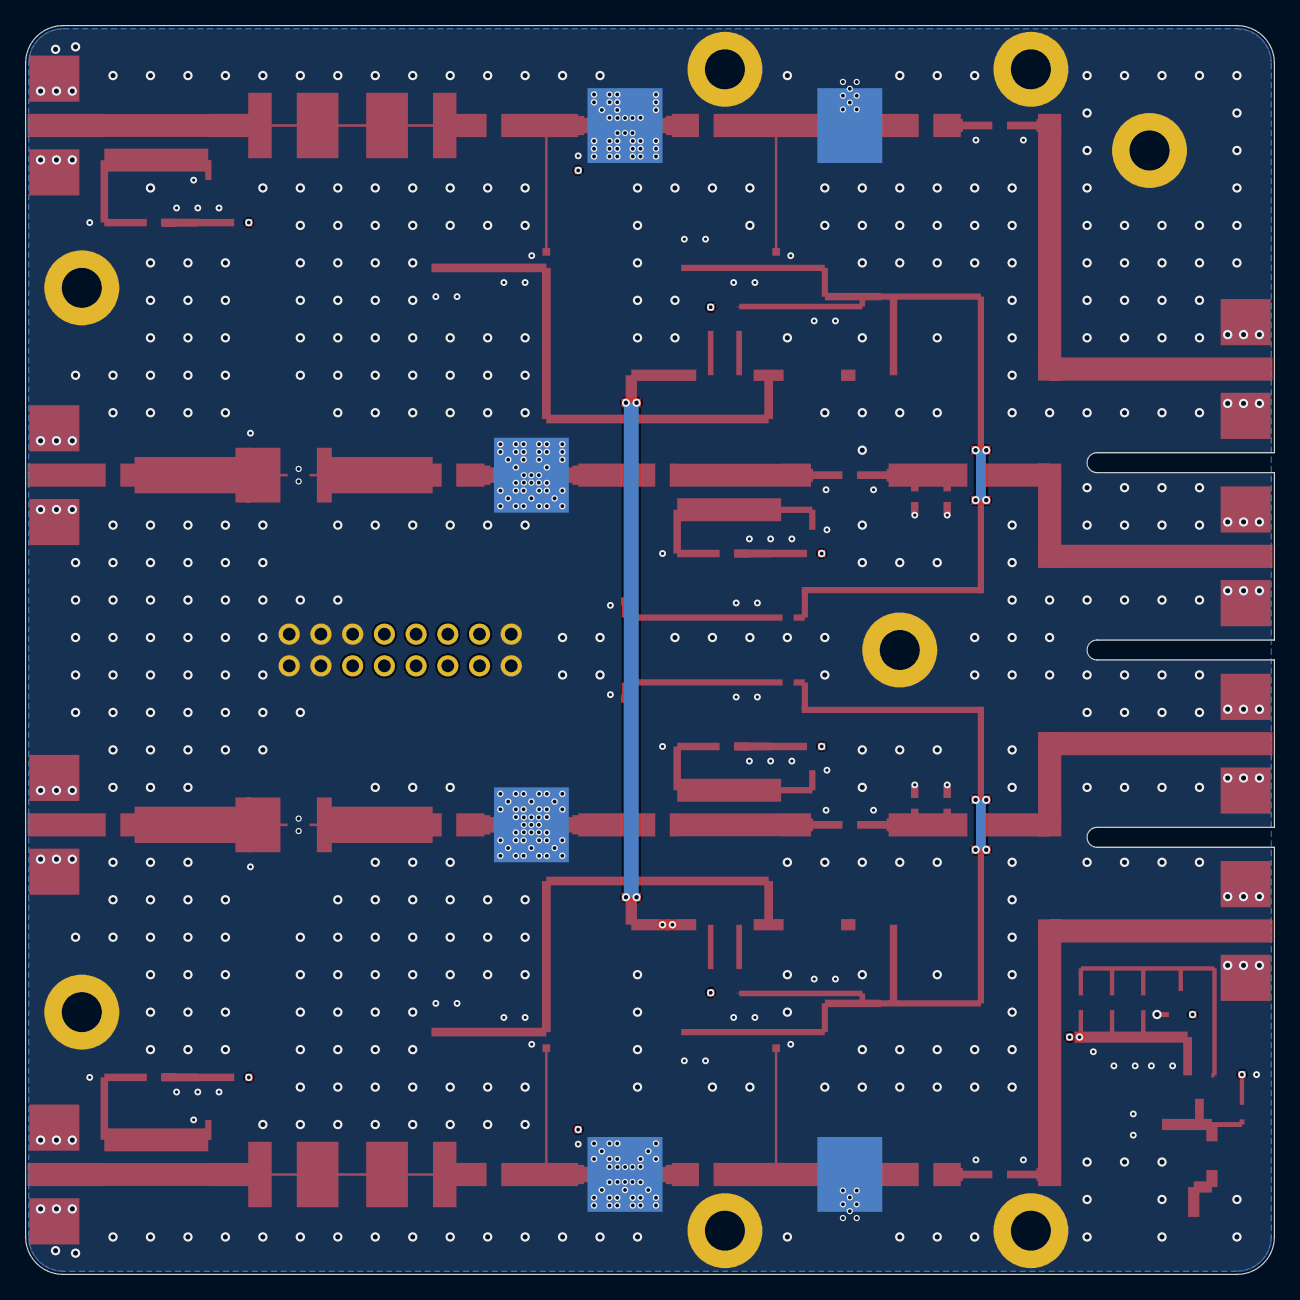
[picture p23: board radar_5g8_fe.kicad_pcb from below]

Board: 4 copper layers, 100.0 x 100.0 mm, 133 parts (6 on the bottom side), 48 nets, no tracks yet.

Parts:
C1, C214: 100n
C29, C212: 22u
CA1, CA2, CA3, CA81, CA91: 1n
CA5, CA83, CA93: 10u
CA80, CA90: 100p
CA82, CA92: 100n
CAD0: 100p
CAD2: 10n
CB1, CB2, CB3, CB81, CB91: 1n
CB5, CB83, CB93: 10u
CB80, CB90: 100p
CB82, CB92: 100n
CBD0: 100p
CBD2: 10n
CC1, CC2, CC3, CC4, CC80: 100p
CC81: 1n
CC82: 100n
CCD0: 100p
CCD2: 10n
CD1, CD2, CD3, CD4, CD80: 100p
CD81: 1n
CD82: 100n
CDD0: 100p
CDD2: 10n
D5: SMBJ15A
D6: 10V
DA1: SMS7630
DB1: SMS7630
DC1: SMS7630
DCC1, DCC2: SMS7630-079LF
DCL: SMP1330-085LF
DD1: SMS7630
DDC1, DDC2: SMS7630-079LF
DDL: SMP1330-085LF
F1: MF-MSMF150
FBC: 600R
FBD: 600R
FID6_97, FID60_3, FID94_97: (no value)
H10_90, H19_3, H19_96, H30_50, H44_3, H44_96, H95_21, H95_79: M3
J1: (no value)
J5: 8x2 2.54 mm header
LDCL: 10n
LDDL: 10n
Q3: AO3401A
Q4: 2N7002
R1: 100k
R2: (no value)
R3: 47k
RAD1: 10k
RAF: 51R
RAI: (no value)
RAO: 1k
RAP1, RAP3: 150R
RAP2: 36R
RAS: (no value)
RAT: 51R
RAV: (no value)
RBD1: 10k
RBF: 51R
RBI: (no value)
RBO: 1k
RBP1, RBP3: 150R
RBP2: 36R
RBS: (no value)
RBT: 51R
RBV: (no value)
RCD1: 10k
RCF: 51R
RCO: 1k
RCP1, RCP3: 120R
RCP2: 51R
RCT: 51R
RDD1: 10k
RDF: 51R
RDO: 1k
RDP1, RDP3: 120R
RDP2: 51R
RDT: 51R
RTA: 10k NTC
RTB: 10k NTC
TP1, TP2, TP3, TP4, TP5, TP6: thermal face
UA1: PHA-1H+
UA3: AMS1117-5.0
UA4: INA181A2IDBVR
UB1: PHA-1H+
UB3: AMS1117-5.0
UB4: INA181A2IDBVR

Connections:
DETA: J5.14, RAO.1
DETB: J5.5, RBO.1
DETC: J5.11, RCO.1
DETD: J5.2, RDO.1
EN: J5.10, Q4.1, R2.2, R3.1
GND: C29.2, C212.2, C214.2, CA5.2, CA80.2, CA81.2, CA82.2, CA83.2, CA90.2, CA91.2, CA92.2, CA93.2, CAD0.2, CAD2.2, CB5.2, CB80.2, CB81.2, CB82.2, CB83.2, CB90.2, CB91.2, CB92.2, CB93.2, CBD0.2, CBD2.2, CC80.2, CC81.2, CC82.2, CCD0.2, CCD2.2, CD80.2, CD81.2, CD82.2, CDD0.2, CDD2.2, D5.2, DCC1.2, DCC2.1, DCL.2, DDC1.2, DDC2.1, DDL.2, FID6_97.1, FID60_3.1, FID94_97.1, H10_90.1, H19_3.1, H19_96.1, H30_50.1, H44_3.1, H44_96.1, H95_21.1, H95_79.1, J1.2, J5.1, J5.6, J5.7, J5.8, J5.9, J5.15, J5.16, LDCL.2, LDDL.2, Q4.2, R3.2, RAD1.2, RAF.2, RAI.2, RAP1.2, RAP3.2, RAT.2, RBD1.2, RBF.2, RBI.2, RBP1.2, RBP3.2, RBT.2, RCD1.2, RCF.2, RCP1.2, RCP3.2, RCT.2, RDD1.2, RDF.2, RDP1.2, RDP3.2, RDT.2, RTA.2, RTB.2, TP1.1, TP2.1, TP3.1, TP4.1, TP5.1, TP6.1, UA1.2, UA1.4, UA3.1, UA4.2, UA4.5, UB1.2, UB1.4, UB3.1, UB4.2, UB4.5
IMONA: J5.12, UA4.1
IMONB: J5.3, UB4.1
RX1_CPL: DC1.2, RCF.1, RCT.1
RX1_CPLM: CC3.1, RCP2.2, RCP3.1
RX1_DETV: CCD0.1, CCD2.1, DC1.1, RCD1.1, RCO.2
RX1_L: CC1.1, DCL.3, LDCL.1
RX1_LI: CC2.2, DCL.1
RX1_P: CC4.2, DCC1.1, DCC2.2, RCP1.1, RCP2.1
RX1_T: CC3.2, CC80.1, CC81.1, CC82.1, FBC.2
RX2_CPL: DD1.2, RDF.1, RDT.1
RX2_CPLM: CD3.1, RDP2.2, RDP3.1
RX2_DETV: CDD0.1, CDD2.1, DD1.1, RDD1.1, RDO.2
RX2_L: CD1.1, DDL.3, LDDL.1
RX2_LI: CD2.2, DDL.1
RX2_P: CD4.2, DDC1.1, DDC2.2, RDP1.1, RDP2.1
RX2_T: CD3.2, CD80.1, CD81.1, CD82.1, FBD.2
TEMPA: J5.13, RTA.1
TEMPB: J5.4, RTB.1
TX1_CPL: DA1.2, RAF.1, RAT.1
TX1_D: CA2.1, CA90.1, UA1.3
TX1_DETV: CAD0.1, CAD2.1, DA1.1, RAD1.1, RAO.2
TX1_DI: CA1.2, UA1.1
TX1_IN: RAP1.1, RAP2.1
TX1_P: CA1.1, RAP2.2, RAP3.1
TX1_PA: CA3.1, CA80.1
TX2_CPL: DB1.2, RBF.1, RBT.1
TX2_D: CB2.1, CB90.1, UB1.3
TX2_DETV: CBD0.1, CBD2.1, DB1.1, RBD1.1, RBO.2
TX2_DI: CB1.2, UB1.1
TX2_IN: RBP1.1, RBP2.1
TX2_P: CB1.1, RBP2.2, RBP3.1
TX2_PA: CB3.1, CB80.1
V5A: CA5.1, CA91.1, CA92.1, CA93.1, FBC.1, UA3.2, UA4.6
V5A_I: RAV.1, UA3.3
V5B: CB5.1, CB91.1, CB92.1, CB93.1, FBD.1, UB3.2, UB4.6
V5B_I: RBV.1, UB3.3
V12: C1.1, C29.1, C212.1, C214.1, D6.1, Q3.2, R1.1, RAS.2, RBS.2, UA4.3, UB4.3
V12A: CA81.1, CA82.1, CA83.1, RAS.1, RAV.2, UA4.4
V12B: CB81.1, CB82.1, CB83.1, RBS.1, RBV.2, UB4.4
V12G: C1.2, D6.2, Q3.1, Q4.3, R1.2
VF: D5.1, F1.2, Q3.3, R2.1
VIN: F1.1, J1.1

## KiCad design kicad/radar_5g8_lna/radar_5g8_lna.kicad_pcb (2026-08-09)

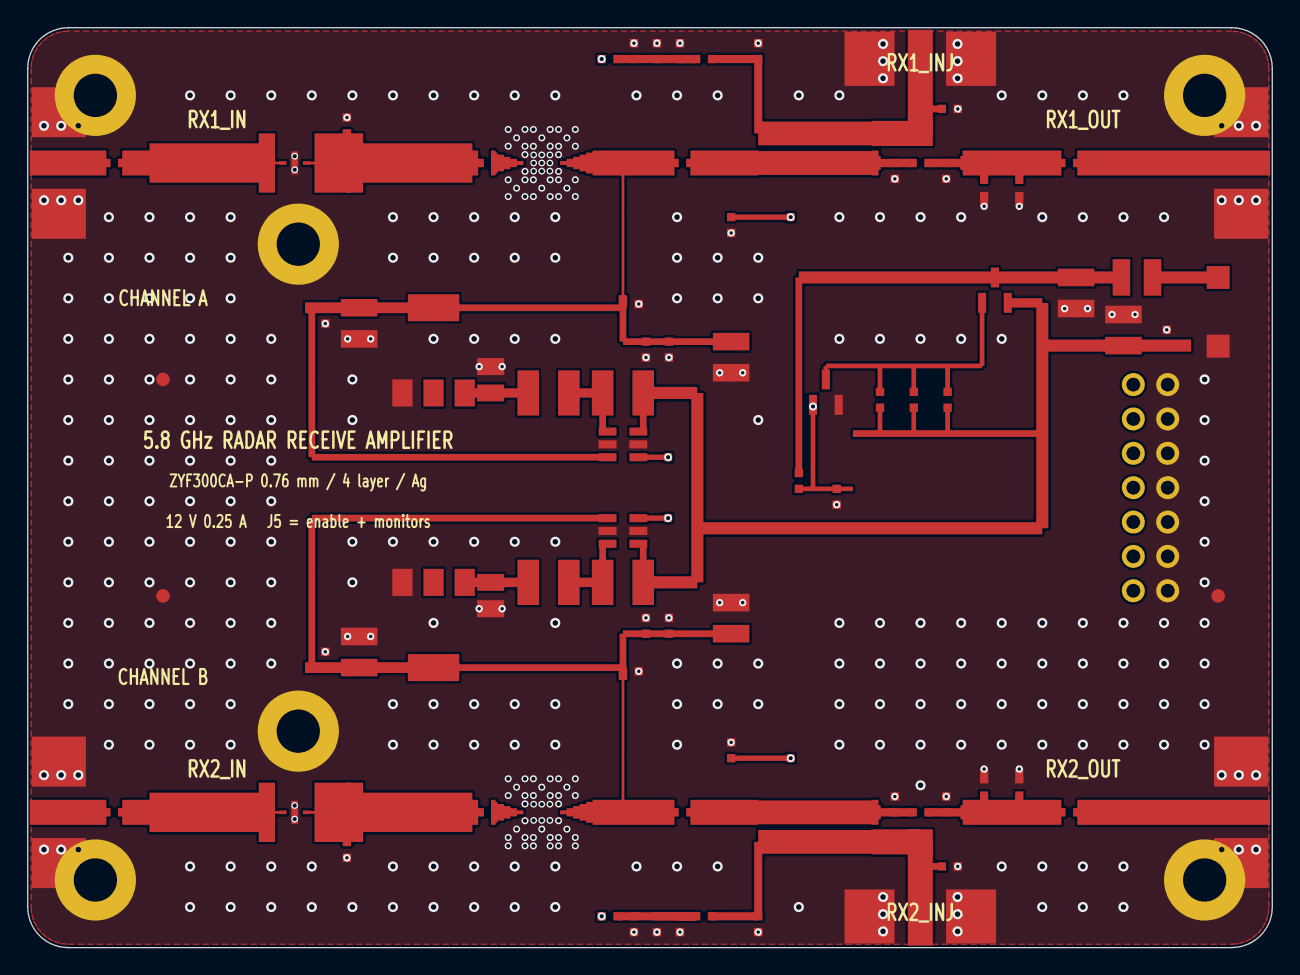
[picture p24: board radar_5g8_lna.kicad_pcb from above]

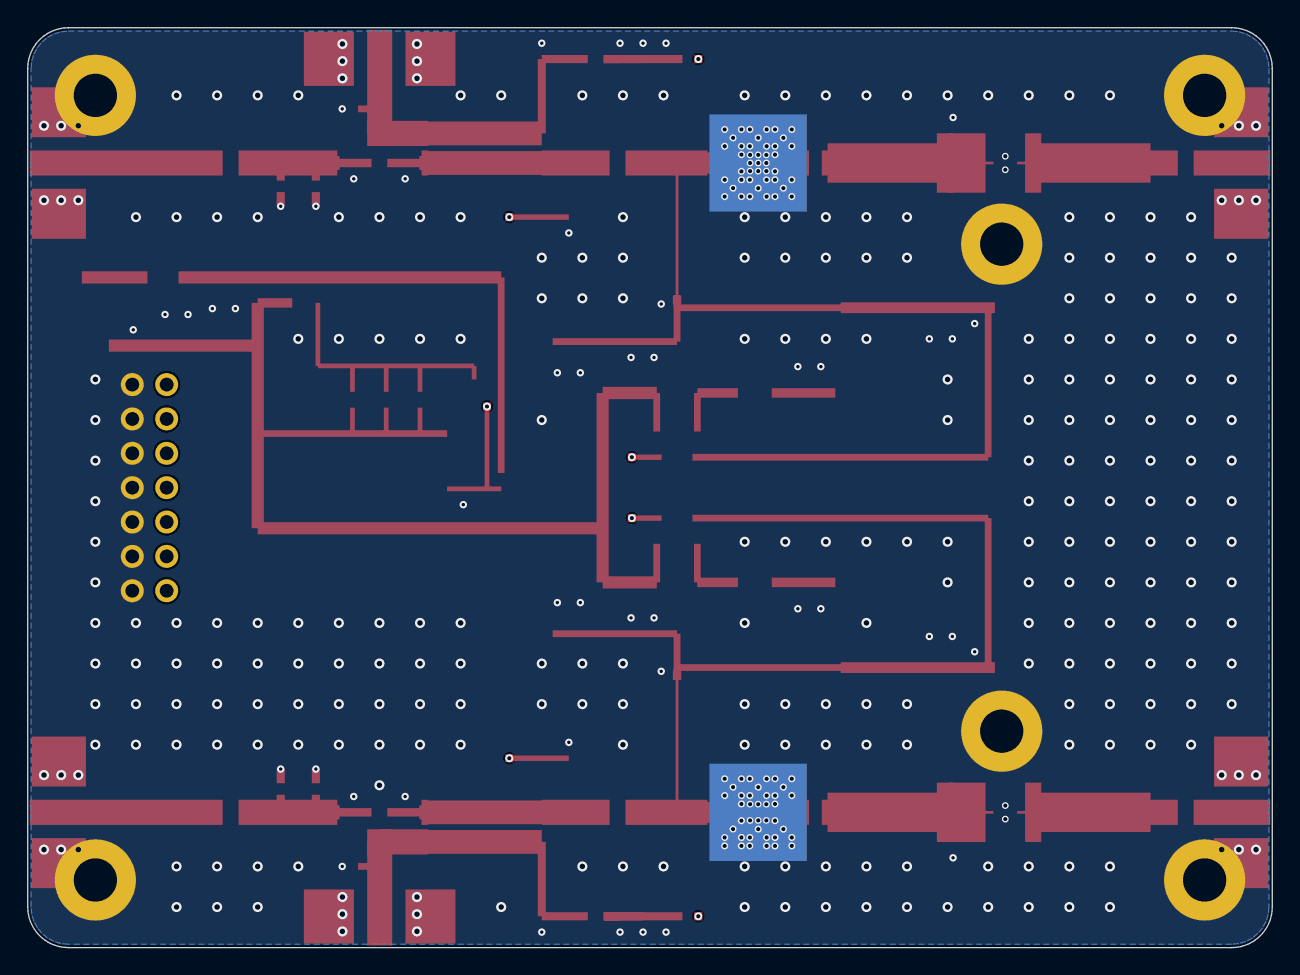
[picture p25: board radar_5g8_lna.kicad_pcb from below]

Board: 4 copper layers, 92.0 x 68.0 mm, 84 parts (2 on the bottom side), 30 nets, no tracks yet.

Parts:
C1, C21: 100n
C20: 22u
CA1, CA2, CA3, CA4, CA80: 100p
CA5, CA6, CA83: 10u
CA7, CA82: 100n
CA81: 1n
CAD0: 100p
CAD2: 10n
CB1, CB2, CB3, CB4, CB80: 100p
CB5, CB6, CB83: 10u
CB7, CB82: 100n
CB81: 1n
CBD0: 100p
CBD2: 10n
D5: SMBJ15A
D6: 10V
DA1: SMS7630
DAC1, DAC2: SMS7630-079LF
DAL: SMP1330-085LF
DB1: SMS7630
DBC1, DBC2: SMS7630-079LF
DBL: SMP1330-085LF
F1: MF-MSMF100
FID10_26, FID10_42, FID88_26: (no value)
H5_5, H5_63, H20_16, H20_52, H87_5, H87_63: M3
J1: (no value)
J5: 2x7 2.54 mm header
LDAL: 10n
LDBL: 10n
Q3: AO3401A
Q4: 2N7002
R1, R2: 100k
R3: 47k
RAD1: 10k
RAJ: 51R
RAO: 1k
RAP1, RAP3: 120R
RAP2: 51R
RAS: (no value)
RAT: 51R
RAV: (no value)
RBD1: 10k
RBJ: 51R
RBO: 1k
RBP1, RBP3: 120R
RBP2: 51R
RBS: (no value)
RBT: 51R
RBV: (no value)
RTA: 10k NTC
RTB: 10k NTC
TP1, TP2: thermal face
UA2: AMS1117-5.0
UA3: INA181A2IDBVR
UB2: AMS1117-5.0
UB3: INA181A2IDBVR

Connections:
DETA: J5.7, RAO.1
DETB: J5.11, RBO.1
EN: J5.1, Q4.1, R2.1, R3.1
GND: C20.2, C21.2, CA5.2, CA6.2, CA7.2, CA80.2, CA81.2, CA82.2, CA83.2, CAD0.2, CAD2.2, CB5.2, CB6.2, CB7.2, CB80.2, CB81.2, CB82.2, CB83.2, CBD0.2, CBD2.2, D5.2, DAC1.2, DAC2.1, DAL.2, DBC1.2, DBC2.1, DBL.2, FID10_26.1, FID10_42.1, FID88_26.1, H5_5.1, H5_63.1, H20_16.1, H20_52.1, H87_5.1, H87_63.1, J1.2, J5.2, J5.4, J5.6, J5.8, J5.10, J5.12, J5.14, LDAL.2, LDBL.2, Q4.2, R3.2, RAD1.2, RAJ.2, RAP1.2, RAP3.2, RAT.2, RBD1.2, RBJ.2, RBP1.2, RBP3.2, RBT.2, RTA.2, RTB.2, TP1.1, TP2.1, UA2.1, UA3.2, UA3.5, UB2.1, UB3.2, UB3.5
IMONA: J5.5, UA3.1
IMONB: J5.9, UB3.1
RX1_CPL: DA1.2, RAJ.1, RAT.1
RX1_CPLM: CA3.2, RAP1.1, RAP2.1
RX1_DETV: CAD0.1, CAD2.1, DA1.1, RAD1.1, RAO.2
RX1_L: CA1.2, DAL.1
RX1_LI: CA2.1, DAL.3, LDAL.1
RX1_P: CA4.1, DAC1.1, DAC2.2, RAP2.2, RAP3.1
RX1_T: CA3.1, CA6.1, CA7.1, CA80.1, CA81.1, CA82.1, CA83.1, UA2.2, UA3.6
RX2_CPL: DB1.2, RBJ.1, RBT.1
RX2_CPLM: CB3.2, RBP1.1, RBP2.1
RX2_DETV: CBD0.1, CBD2.1, DB1.1, RBD1.1, RBO.2
RX2_L: CB1.2, DBL.1
RX2_LI: CB2.1, DBL.3, LDBL.1
RX2_P: CB4.1, DBC1.1, DBC2.2, RBP2.2, RBP3.1
RX2_T: CB3.1, CB6.1, CB7.1, CB80.1, CB81.1, CB82.1, CB83.1, UB2.2, UB3.6
TEMPA: J5.3, RTA.1
TEMPB: J5.13, RTB.1
V5A_I: CA5.1, RAV.1, UA2.3
V5B_I: CB5.1, RBV.1, UB2.3
V12: C1.1, C20.1, C21.1, D6.1, Q3.2, R1.1, RAS.2, RBS.2, UA3.3, UB3.3
V12A: RAS.1, RAV.2, UA3.4
V12B: RBS.1, RBV.2, UB3.4
V12G: C1.2, D6.2, Q3.1, Q4.3, R1.2
VF: D5.1, F1.1, Q3.3, R2.2
VIN: F1.2, J1.1

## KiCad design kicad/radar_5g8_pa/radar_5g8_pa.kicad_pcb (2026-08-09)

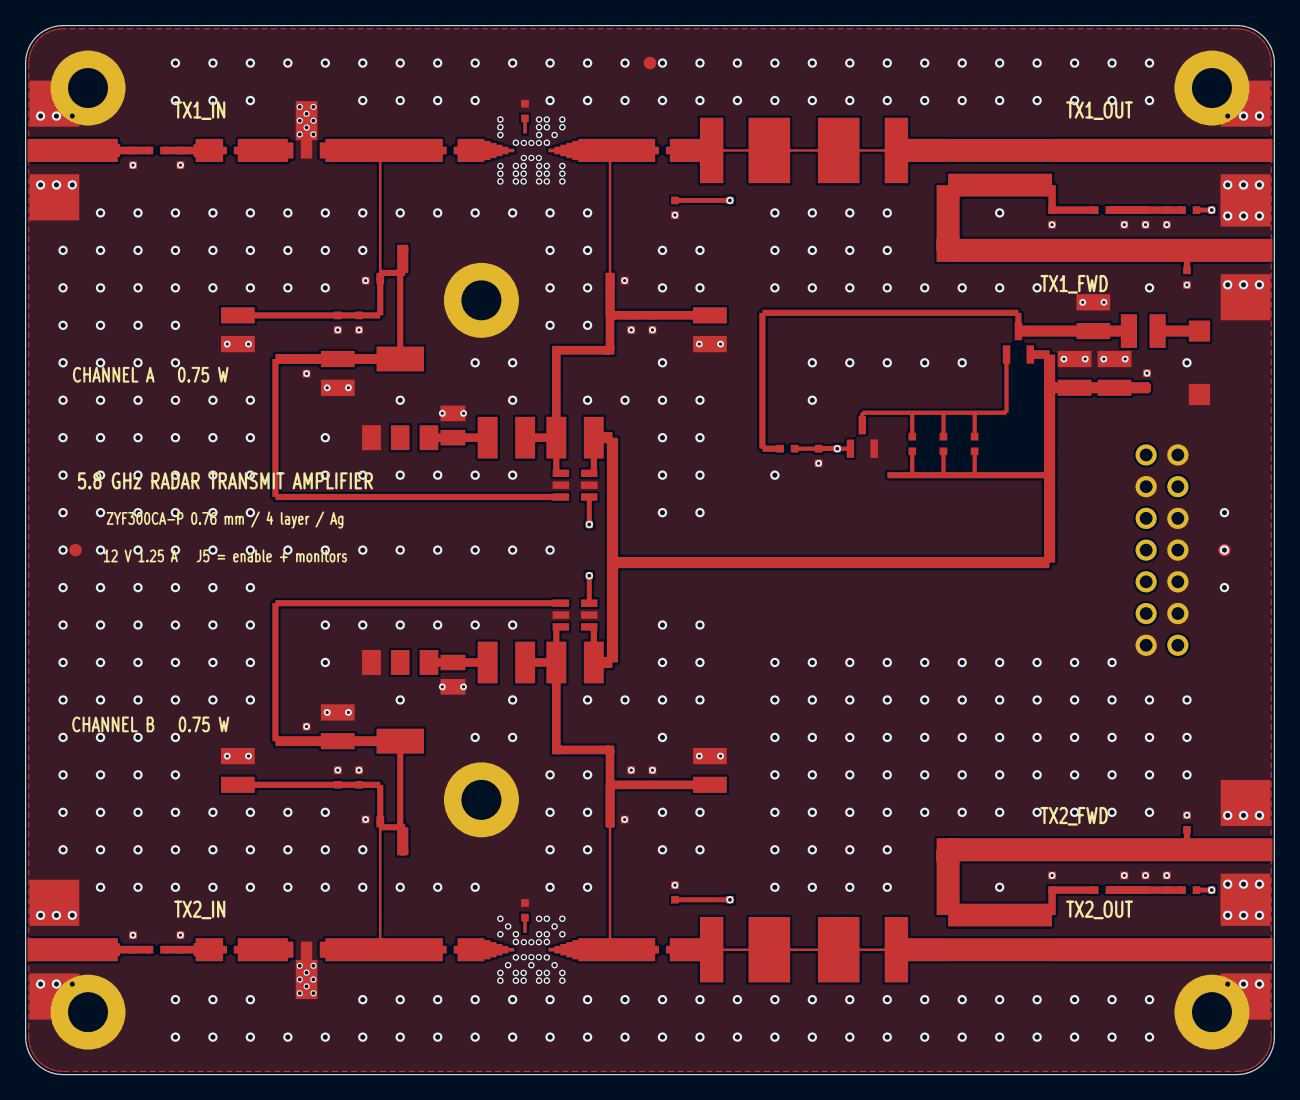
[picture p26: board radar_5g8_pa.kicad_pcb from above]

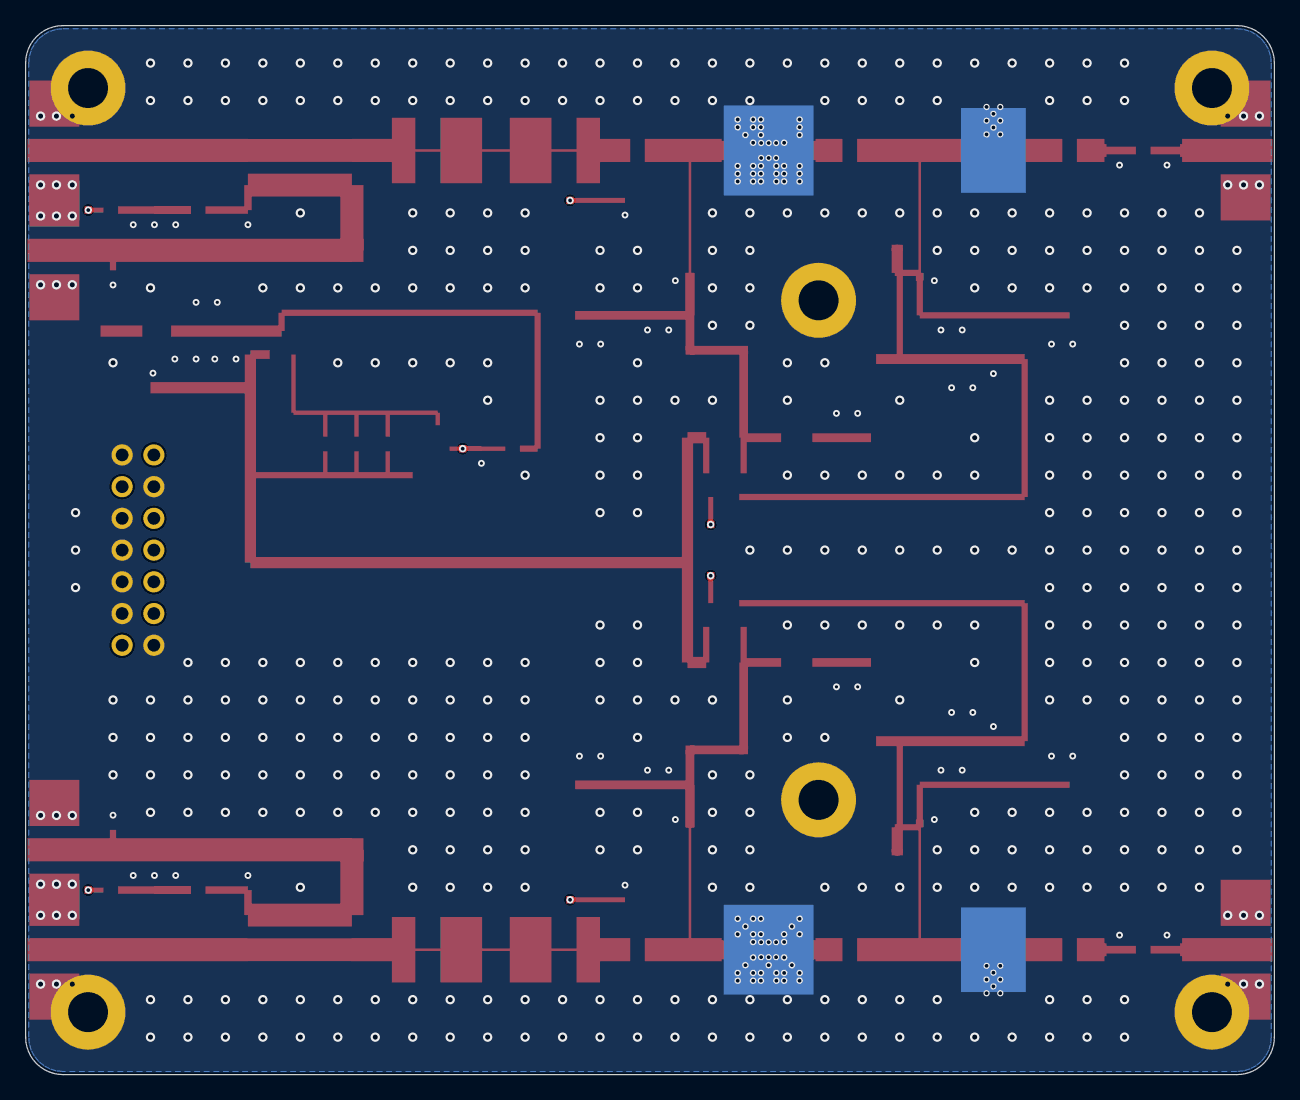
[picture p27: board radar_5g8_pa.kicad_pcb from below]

Board: 4 copper layers, 100.0 x 84.0 mm, 89 parts (4 on the bottom side), 28 nets, no tracks yet.

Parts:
C1, C22: 100n
C20, C21: 22u
CA1, CA2, CA3, CA81, CA91: 1n
CA5, CA6, CA83, CA93: 10u
CA7, CA82, CA92: 100n
CA80, CA90: 100p
CAD0: 100p
CAD2: 10n
CB1, CB2, CB3, CB81, CB91: 1n
CB5, CB6, CB83, CB93: 10u
CB7, CB82, CB92: 100n
CB80, CB90: 100p
CBD0: 100p
CBD2: 10n
D5: SMBJ15A
D6: 10V
DA1: SMS7630
DB1: SMS7630
F1: MF-MSMF150
FID4_42, FID50_81, FID96_42: (no value)
H5_5, H5_79, H36_22, H36_62, H95_5, H95_79: M3
J1: (no value)
J5: 2x7 2.54 mm header
Q3: AO3401A
Q4: 2N7002
R1, R2: 100k
R3: 47k
RAD1: 10k
RAF: 51R
RAI: (no value)
RAO: 1k
RAP1, RAP3: 150R
RAP2: 36R
RAS: (no value)
RAT: 51R
RAV: (no value)
RBD1: 10k
RBF: 51R
RBI: (no value)
RBO: 1k
RBP1, RBP3: 150R
RBP2: 36R
RBS: (no value)
RBT: 51R
RBV: (no value)
RTA: 10k NTC
RTB: 10k NTC
TP1, TP2, TP3, TP4: thermal face
UA1: PHA-1H+
UA3: AMS1117-5.0
UA4: INA181A2IDBVR
UB1: PHA-1H+
UB3: AMS1117-5.0
UB4: INA181A2IDBVR

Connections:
DETA: J5.4, RAO.2
DETB: J5.14, RBO.2
EN: J5.1, Q4.1, R2.2, R3.1
GND: C20.2, C21.2, C22.2, CA5.2, CA6.2, CA7.2, CA80.2, CA81.2, CA82.2, CA83.2, CA90.2, CA91.2, CA92.2, CA93.2, CAD0.2, CAD2.2, CB5.2, CB6.2, CB7.2, CB80.2, CB81.2, CB82.2, CB83.2, CB90.2, CB91.2, CB92.2, CB93.2, CBD0.2, CBD2.2, D5.2, FID4_42.1, FID50_81.1, FID96_42.1, H5_5.1, H5_79.1, H36_22.1, H36_62.1, H95_5.1, H95_79.1, J1.2, J5.2, J5.3, J5.6, J5.8, J5.10, J5.12, J5.13, Q4.2, R3.2, RAD1.2, RAF.2, RAI.2, RAP1.2, RAP3.2, RAT.2, RBD1.2, RBF.2, RBI.2, RBP1.2, RBP3.2, RBT.2, RTA.2, RTB.2, TP1.1, TP2.1, TP3.1, TP4.1, UA1.2, UA1.4, UA3.1, UA4.2, UA4.5, UB1.2, UB1.4, UB3.1, UB4.2, UB4.5
IMONA: J5.7, UA4.1
IMONB: J5.9, UB4.1
TEMPA: J5.5, RTA.1
TEMPB: J5.11, RTB.1
TX1_CPL: DA1.1, RAF.1, RAT.1
TX1_D: CA2.1, CA6.1, CA7.1, CA90.1, CA91.1, CA92.1, CA93.1, UA1.3, UA3.2, UA4.6
TX1_DETV: CAD0.1, CAD2.1, DA1.2, RAD1.1, RAO.1
TX1_DI: CA1.2, UA1.1
TX1_IN: RAP1.1, RAP2.1
TX1_P: CA1.1, RAP2.2, RAP3.1
TX1_PA: CA3.1, CA80.1, CA81.1, CA82.1, CA83.1, RAS.1, RAV.2, UA4.4
TX2_CPL: DB1.1, RBF.1, RBT.1
TX2_D: CB2.1, CB6.1, CB7.1, CB90.1, CB91.1, CB92.1, CB93.1, UB1.3, UB3.2, UB4.6
TX2_DETV: CBD0.1, CBD2.1, DB1.2, RBD1.1, RBO.1
TX2_DI: CB1.2, UB1.1
TX2_IN: RBP1.1, RBP2.1
TX2_P: CB1.1, RBP2.2, RBP3.1
TX2_PA: CB3.1, CB80.1, CB81.1, CB82.1, CB83.1, RBS.1, RBV.2, UB4.4
V5A_I: CA5.1, RAV.1, UA3.3
V5B_I: CB5.1, RBV.1, UB3.3
V12: C1.1, C20.1, C21.1, C22.1, D6.1, Q3.2, R1.1, RAS.2, RBS.2, UA4.3, UB4.3
V12G: C1.2, D6.2, Q3.1, Q4.3, R1.2
VF: D5.1, F1.1, Q3.3, R2.1
VIN: F1.2, J1.1

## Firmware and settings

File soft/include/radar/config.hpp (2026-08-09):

//============================================================================
// config.hpp -- the radar's operating point, in one struct
//
// Mirrors fpga/rtl/radar_pkg.svh.  Anything that would need the FPGA rebuilt
// is a compile-time constant there and a default here; anything settable over
// the settings bus is a field.  derive() fills in every quantity that follows
// from the others, so nothing downstream ever recomputes a range scale or a
// Doppler bin width for itself.
//============================================================================
#pragma once

#include "radar/core.hpp"
#include <string>

namespace radar {

enum class MimoMode : int { Tdm = 0, Ddm = 1, Tx0Only = 2, Tx1Only = 3 };
enum class CfarKind : int { Ca = 0, Go = 1, So = 2, Os = 3, None = 4 };
enum class WindowKind : int { Rect, Hann, Hamming, BlackmanHarris, Taylor, Chebyshev };
enum class AoaMethod : int { Monopulse, Bartlett, Capon, Music };

/// Where the IQ (or already-processed frames) come from.
enum class SourceKind : int {
    Simulate,   ///< synthetic scene through the bit-exact model -- no hardware
    Uhd,        ///< a real B210 running the radar gateware
    File,       ///< replay of a recording
};

struct Config {
    //------------------------------------------------------------------
    // Front end
    //------------------------------------------------------------------
    SourceKind  source          = SourceKind::Simulate;
    std::string device_args     = "type=b200";
    double      centre_freq_hz  = 5.800e9;
    double      sample_rate_hz  = 61.44e6;   ///< AD9361 master clock
    double      tx_gain_db      = 70.0;      ///< B210 TX gain, 0..89.75
    double      rx_gain_db      = 40.0;      ///< B210 RX gain, 0..76
    double      rx_bandwidth_hz = 56.0e6;    ///< AD9361 analogue filter
    std::string clock_source    = "internal";
    std::string time_source     = "internal";

    //------------------------------------------------------------------
    // Waveform.  Defaults are the operating point radar-plan computes as
    // optimal for this array, this radio and a small-drone target.
    //------------------------------------------------------------------
    double   sweep_bw_hz   = 50.0e6;   ///< linear-FM sweep width
    int      n_sweep       = 3072;     ///< sweep length, radio clocks
    int      n_pri         = 3840;     ///< pulse repetition interval, clocks
    int      n_chirp       = 128;      ///< chirps per transmitter per CPI
    MimoMode mimo          = MimoMode::Tdm;
    bool     tx_enable     = true;

    //------------------------------------------------------------------
    // Transform chain
    //------------------------------------------------------------------
    int        decim         = 4;      ///< halfband cascade, 61.44 -> 15.36 MSps
    int        n_range_fft   = 1024;
    /// n_range * n_chirp_total is fixed at 65536 by the on-chip corner-turn
    /// buffer -- see the memory note in fpga/rtl/radar_pkg.svh. validate()
    /// enforces it, so raising one of these lowers the other.
    int        n_range       = 256;    ///< range bins kept and streamed
    int        n_doppler     = 128;    ///< equals n_chirp in TDM
    WindowKind range_window  = WindowKind::BlackmanHarris;
    WindowKind dopp_window   = WindowKind::BlackmanHarris;

    //------------------------------------------------------------------
    // Detection
    //------------------------------------------------------------------
    CfarKind cfar_kind    = CfarKind::Ca;
    int      guard_range  = 2;
    int      guard_dopp   = 2;
    int      train_range  = 6;
    int      train_dopp   = 6;
    double   pfa          = 1e-5;
    int      max_hits     = 512;
    int      zero_dopp_blank = 2;   ///< Doppler bins each side of DC to ignore
    int      range_zero_bin  = 0;   ///< bin of the transmit-leakage peak

    //------------------------------------------------------------------
    // Angle, clustering, tracking
    //------------------------------------------------------------------
    AoaMethod aoa            = AoaMethod::Music;
    int       aoa_az_bins    = 181;
    int       aoa_el_bins    = 91;
    double    aoa_az_span_deg = 90.0;   ///< +/- this
    double    aoa_el_span_deg = 45.0;
    double    cluster_eps_m  = 8.0;
    double    cluster_eps_ms = 2.0;
    double    cluster_eps_deg = 10.0;
    int       cluster_min_pts = 1;
    double    track_gate_chi2 = 16.0;   ///< 3 dof, ~99.9%
    int       track_confirm_n = 3;
    int       track_drop_n    = 5;
    double    track_q_accel   = 12.0;   ///< process noise, m/s^2, drone-agile
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

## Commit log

2026-08-09 Initial commit: complete 5.8 GHz 2x2 MIMO radar array project
    [BOM.csv, PLACEMENT.csv, carrier.scad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]
2026-08-09 Auto-update: 2026-08-09 20:05:31
    [BOM.csv, PLACEMENT.csv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]
2026-08-09 Auto-update: 2026-08-09 20:05:39
    [radar_5g8_fe-B_Cu.gbr, radar_5g8_fe-B_Mask.gbr, radar_5g8_fe-Edge_Cuts.gbr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]
2026-08-09 Auto-update: 2026-08-09 20:05:46
    [radar_5g8_fe-B_Cu.gbr, radar_5g8_fe-B_Mask.gbr, radar_5g8_fe-Edge_Cuts.gbr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]
2026-08-09 Auto-update: 2026-08-09 20:05:53
    [radar_5g8_fe-B_Cu.gbr, radar_5g8_fe-B_Mask.gbr, radar_5g8_fe-Edge_Cuts.gbr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]
2026-08-09 Auto-update: 2026-08-09 20:05:59
    [radar_5g8_fe-job.gbrjob, radar_5g8_fe.drl]
2026-08-09 Auto-update: 2026-08-09 20:10:42
    [radar_5g8_fe-B_Cu.gbr, radar_5g8_fe-B_Mask.gbr, radar_5g8_fe-Edge_Cuts.gbr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]
2026-08-09 Auto-update: 2026-08-09 20:11:08
    [radar_5g8_fe-B_Cu.gbr, radar_5g8_fe-B_Mask.gbr, radar_5g8_fe-Edge_Cuts.gbr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]
2026-08-09 Auto-update: 2026-08-09 20:12:01
    [radar_5g8_fe.kicad_pcb]
2026-08-09 Auto-update: 2026-08-09 20:12:08
    [PLACEMENT.csv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]
2026-08-09 Auto-update: 2026-08-09 20:13:34
    [radar_5g8_pa-B_Cu.gbr, radar_5g8_pa-B_Mask.gbr, radar_5g8_pa-Edge_Cuts.gbr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]
2026-08-09 Auto-update: 2026-08-09 20:14:38
    [PLACEMENT.csv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]
2026-08-09 Auto-update: 2026-08-09 20:16:17
    [radar_5g8_fe-B_Cu.gbr, radar_5g8_fe-B_Mask.gbr, radar_5g8_fe-Edge_Cuts.gbr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]
2026-08-09 Auto-update: 2026-08-09 20:17:23
    [radar_5g8_receive-NPTH-drl_map.gbr, radar_5g8_receive-NPTH.drl, radar_5g8_receive-PTH-drl_map.gbr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]
2026-08-09 Auto-update: 2026-08-09 20:17:55
    [radar_5g8_fe-B_Cu.gbr, radar_5g8_fe-B_Mask.gbr, radar_5g8_fe-Edge_Cuts.gbr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]
2026-08-09 Auto-update: 2026-08-09 20:18:09
    [radar_5g8_receive.kicad_pcb, radar_5g8_transmit.kicad_pcb]
2026-08-09 Auto-update: 2026-08-09 20:18:46
    [radar_5g8_fe-B_Cu.gbr, radar_5g8_fe-B_Mask.gbr, radar_5g8_fe-Edge_Cuts.gbr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]
2026-08-09 Auto-update: 2026-08-09 20:18:59
    [radar_5g8_receive.kicad_pcb, radar_5g8_transmit.kicad_pcb]
2026-08-09 Auto-update: 2026-08-09 20:19:23
    [radar_5g8_fe.kicad_pcb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]
2026-08-09 Auto-update: 2026-08-09 20:19:30
    [radar_5g8_fe-B_Cu.gbr, radar_5g8_fe-B_Mask.gbr, radar_5g8_fe-Edge_Cuts.gbr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]
2026-08-09 Auto-update: 2026-08-09 20:20:45
    [radar_5g8_fe-B_Cu.gbr, radar_5g8_fe-B_Mask.gbr, radar_5g8_fe-Edge_Cuts.gbr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]
2026-08-09 Auto-update: 2026-08-09 20:21:04
    [radar_5g8_lna.kicad_pcb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]
2026-08-09 Auto-update: 2026-08-09 20:21:11
    [radar_5g8_lna-B_Cu.gbr, radar_5g8_lna-B_Mask.gbr, radar_5g8_lna-Edge_Cuts.gbr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]
2026-08-09 Auto-update: 2026-08-09 20:23:08
    [BOM.csv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]
2026-08-09 Auto-update: 2026-08-09 20:24:15
    [radar_5g8_receive.kicad_pcb, radar_5g8_transmit.kicad_pcb]
2026-08-09 Auto-update: 2026-08-09 20:26:15
    [radar_5g8_receive.kicad_pcb, radar_5g8_transmit.kicad_pcb]
2026-08-09 Auto-update: 2026-08-09 20:26:43
    [radar_5g8_receive.kicad_pcb, radar_5g8_transmit.kicad_pcb]
2026-08-09 Auto-update: 2026-08-09 20:26:55
    [radar_5g8_transmit.kicad_pcb]
2026-08-09 Auto-update: 2026-08-09 20:27:19
    [radar_5g8_receive.kicad_pcb, radar_5g8_transmit.kicad_pcb]
2026-08-09 Auto-update: 2026-08-09 20:27:49
    [radar_5g8_receive.kicad_pcb, radar_5g8_transmit.kicad_pcb]
2026-08-09 Auto-update: 2026-08-09 20:28:49
    [radar_5g8_receive.kicad_pcb, radar_5g8_transmit.kicad_pcb]
2026-08-09 Auto-update: 2026-08-09 20:29:29
    [radar_5g8_receive-B_Adhesive.gbr, radar_5g8_receive-B_Courtyard.gbr, radar_5g8_receive-B_Cu.gbr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]
2026-08-09 Auto-update: 2026-08-09 20:31:39
    [radar_5g8_receive_array_MECHANICAL.dxf, radar_5g8_receive_array_bom_jlcpcb.csv, radar_5g8_transmit_array_MECHANICAL.dxf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]
2026-08-09 Auto-update: 2026-08-09 20:31:58
    [BOM_receive.csv, BOM_transmit.csv]
2026-08-09 Auto-update: 2026-08-09 20:32:22
    [BOM.csv]
2026-08-09 Auto-update: 2026-08-09 20:32:40
    [BOM.csv]
2026-08-09 Auto-update: 2026-08-09 20:33:10
    [carrier.scad, plate_receive.dxf, plate_transmit.dxf]
2026-08-09 Auto-update: 2026-08-09 20:33:28
    [half_transmit.stl]
2026-08-09 Auto-update: 2026-08-09 20:33:51
    [half_receive.stl]
2026-08-09 Auto-update: 2026-08-09 20:34:06
    [BOM.csv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]
2026-08-09 Auto-update: 2026-08-09 20:34:29
    [shelf.stl]
2026-08-09 Auto-update: 2026-08-09 20:35:10
    [half_transmit.stl]
2026-08-09 Auto-update: 2026-08-09 20:35:37
    [half_receive.stl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]
2026-08-09 Auto-update: 2026-08-09 20:35:44
    [BOM.csv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]
2026-08-09 Auto-update: 2026-08-09 20:36:00
    [BOM.csv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]
2026-08-09 Auto-update: 2026-08-09 20:36:16
    [radar_5g8_fe-B_Cu.gbr, radar_5g8_fe-B_Mask.gbr, radar_5g8_fe-Edge_Cuts.gbr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]
2026-08-09 Auto-update: 2026-08-09 20:36:23
    [radar_5g8_fe-job.gbrjob]
2026-08-09 Auto-update: 2026-08-09 20:36:39
    [shelf.stl]
2026-08-09 Auto-update: 2026-08-09 20:37:10
    [plate_receive.dxf, plate_transmit.dxf]
2026-08-09 Auto-update: 2026-08-09 20:37:17
    [radar_5g8_pa-B_Cu.gbr, radar_5g8_pa-B_Mask.gbr, radar_5g8_pa-Edge_Cuts.gbr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]
2026-08-09 Auto-update: 2026-08-09 20:37:25
    [radar_5g8_pa-job.gbrjob]
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

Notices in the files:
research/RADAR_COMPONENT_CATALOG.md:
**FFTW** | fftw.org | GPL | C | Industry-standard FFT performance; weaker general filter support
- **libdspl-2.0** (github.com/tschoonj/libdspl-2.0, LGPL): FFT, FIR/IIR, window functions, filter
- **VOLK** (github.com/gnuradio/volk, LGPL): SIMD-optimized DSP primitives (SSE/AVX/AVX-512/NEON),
